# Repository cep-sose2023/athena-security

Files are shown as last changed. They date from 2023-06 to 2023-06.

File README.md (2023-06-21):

#  🎲 True Random Number Generator (TRNG) with PTG.2 Quality

Welcome to our GitHub page for the True Random Number Generator (TRNG) with PTG.2 quality standard. To ensure the quality of the random numbers, a creative noise source must be selected for each project, and the resulting random numbers must be digitized and processed according to the PTG.2 quality standard. The TRNG project includes three main components:

- **[NodeMCU: Sensor Data Sender](02-Microcontroller):** An Arduino sketch written in C++ for a NodeMCU development board that controls an LED and a fan, reads analog sensor data, and sends this data over a serial interface.
- **[Backend: Python Flask API](03-API):** A Python Flask API that supports system control, generates random numbers, and supports file downloads.
- **[Frontend: Angular Single-Page Application](04-Frontend):** An Angular Single-Page Application (SPA) that provides a user interface for system control, generating random numbers, and downloading files.

Each of these components has its own README file detailing its purpose, installation instructions, and usage. This README file serves as an overview of the entire project, and provides navigation to the individual component README files for more detailed instructions.

## ⭐ Features

The TRNG includes the following features:

- **System Control**: Ability to initialize, shut down, and restart the system.
- **Generate Random Numbers**: Generate random numbers based on user-provided parameters (number of bits and quantity).
- **Download Files**: Generate downloadable files of random numbers by specifying the number of bits and file type (binary or text).
- **Hardware Control and Data Transmission**: Ability to control an LED and a fan, read analog sensor data, and send this data over a serial interface using a NodeMCU board.

## 🛠️ Installation

Each component of the TRNG has its own installation instructions. Please refer to the individual README files for detailed installation steps:

- [NodeMCU: Sensor Data Sender  - Installation Instructions](02-Microcontroller#%EF%B8%8F-installation)
- [Backend: Python Flask API - Installation Instructions](03-API#%EF%B8%8F-installation)
- [Frontend: Angular Single-Page Application - Installation Instructions](04-Frontend#%EF%B8%8F-installation)

---

###  📸 Pictures

TRNG1
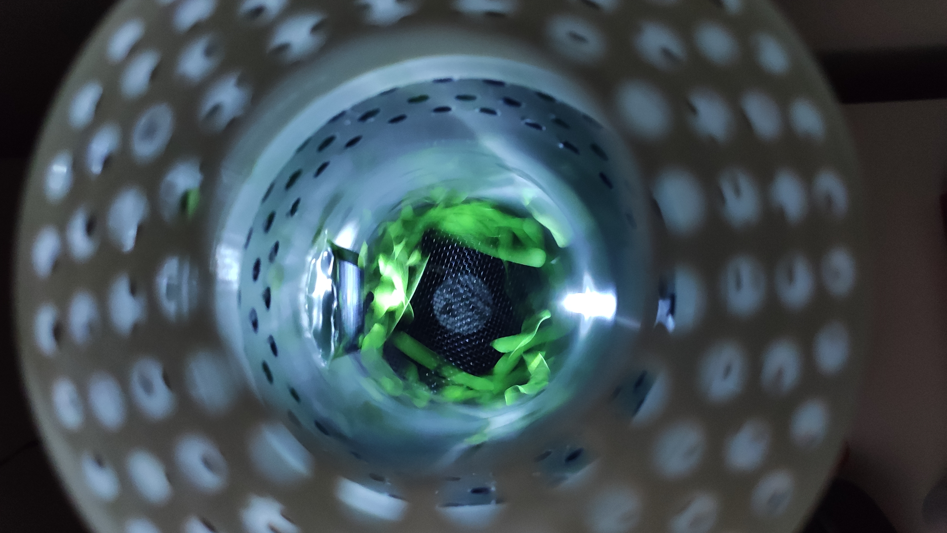
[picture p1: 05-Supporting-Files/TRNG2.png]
TRNG2


---

### 📖 License

This project is licensed under the MIT License. See the [LICENSE](LICENSE) file for details.

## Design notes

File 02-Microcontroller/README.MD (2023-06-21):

# TRNG: NodeMCU Sensor Data Sender

This is an Arduino sketch written in C++ for a NodeMCU development board, a low-cost open-source IoT platform. It leverages built-in functionalities of the NodeMCU to control an LED and a fan, read analog sensor data, and send this data over a serial interface. The program reads the solar voltage from a sensor, extracts the least significant bits (LSBs), and sends them over the serial interface.

## 🖨️ Technologies Used

This project is built using:

- **Arduino IDE:** A software platform used for writing and uploading code to development boards, which are part of electronics projects. The Arduino IDE provides a comprehensive toolset for microcontroller programming, simplifying the process of coding and debugging.
- **C++:** The main programming language used in the Arduino IDE.
- **NodeMCU:** An open-source IoT platform. It includes firmware which runs on the ESP8266 Wi-Fi SoC from Espressif Systems, and hardware which is based on the ESP-12 module.

## ⭐ Features

The NodeMCU code includes the following features:

- 🖥️ **LED & Fan Control:** Ability to turn ON and OFF the LED and the fan by receiving commands over the serial interface.
- 📊 **Analog Sensor Reading:** The program reads the solar voltage from an analog sensor, processes the reading, and converts it to an integer.
- 📡 **Data Transmission:** The program transmits the processed sensor data over the serial interface.

## 🛠️ Installation

This project was written in the Arduino IDE. To run the code on your NodeMCU, make sure you have the following requirements:

- **Arduino IDE:** Arduino IDE is a software used to write and upload the program to the NodeMCU board. Download and install Arduino IDE from the [official website](https://www.arduino.cc/en/software).
- **NodeMCU ESP8266:** The sketch is intended to be run on a NodeMCU board. You can purchase the board from any reputed electronics supplier.

 After you have the necessary tools, follow these steps:

1. **Clone the repository:**

   ```bash
   git clone https://github.com/athena-security/cep.git
   ```

2. **Open the sketch in the Arduino IDE:** Navigate to the downloaded location and open the "nodemcu.ino" file.

3. **Set up the board:** Go to File > Preferences, in the "Additional Boards Manager URLs" field, add this link: "http://arduino.esp8266.com/stable/package_esp8266com_index.json" and click OK. Now, go to Tools > Board > Boards Manager, search for ESP8266 and install it. 

4. **Select the board:** Go to Tools > Board > ESP8266 Boards > NodeMCU 1.0 (ESP-12E Module).

5. **Select the port:** Go to Tools > Port > Select the COM Port that the NodeMCU is connected to.

6. **Upload the sketch:** Click on the upload button (->) or select Sketch > Upload from the menu.

Once the upload is complete, the LED and the fan should respond to "on" and "off" commands sent over the serial interface, and transmit processed sensor data when active.

⚠️ Note: Ensure you have the necessary components and have configured the NodeMCU board correctly before uploading the code. A complete construction manual with a schematic also exists in this repository.

## License

This project is licensed under the [MIT License](../LICENSE.md).

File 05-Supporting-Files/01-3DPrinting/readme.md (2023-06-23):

The visible cover must be printed together with a closure. Both STL-files for 3D printing can be downloaded here. In addition, the files for Autodesk Fusion 360 can also be downloaded here to customize both parts if needed.
<br><br><br>
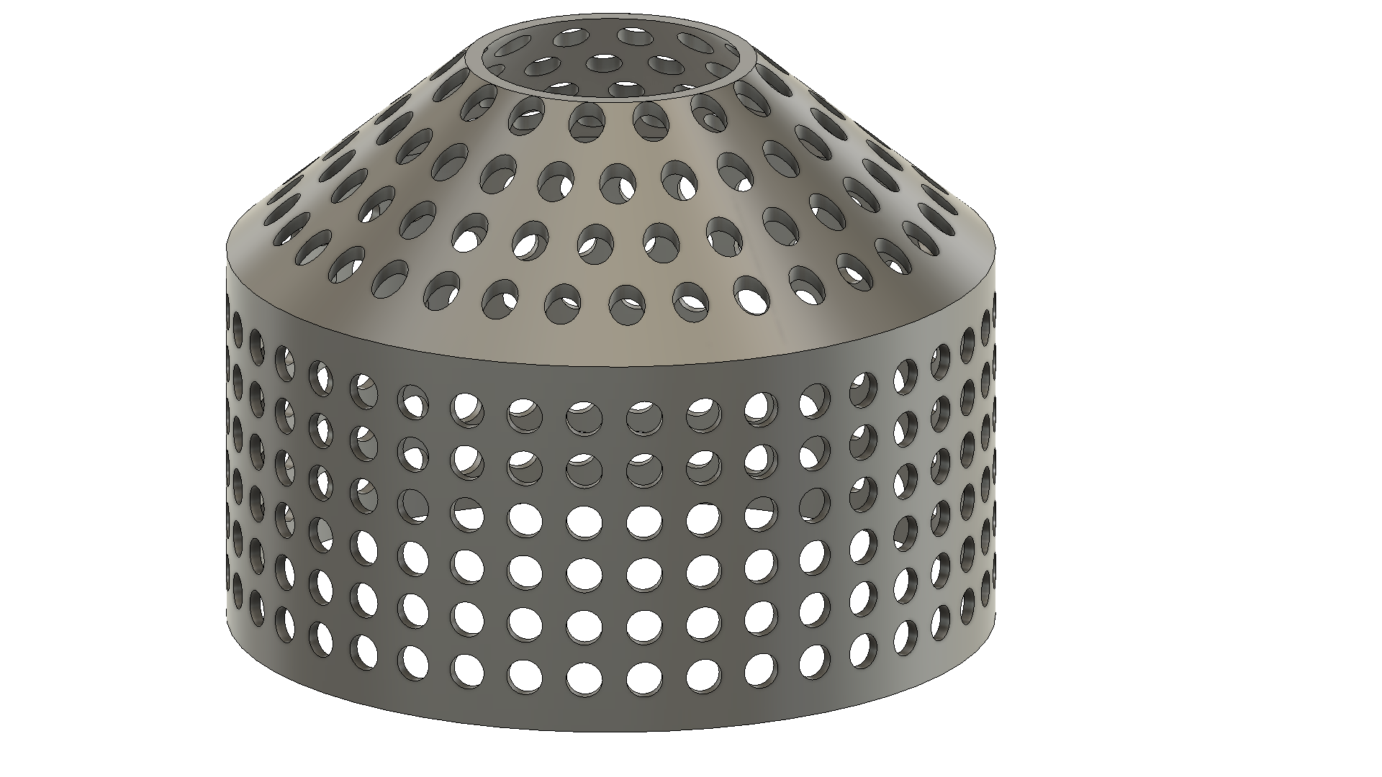
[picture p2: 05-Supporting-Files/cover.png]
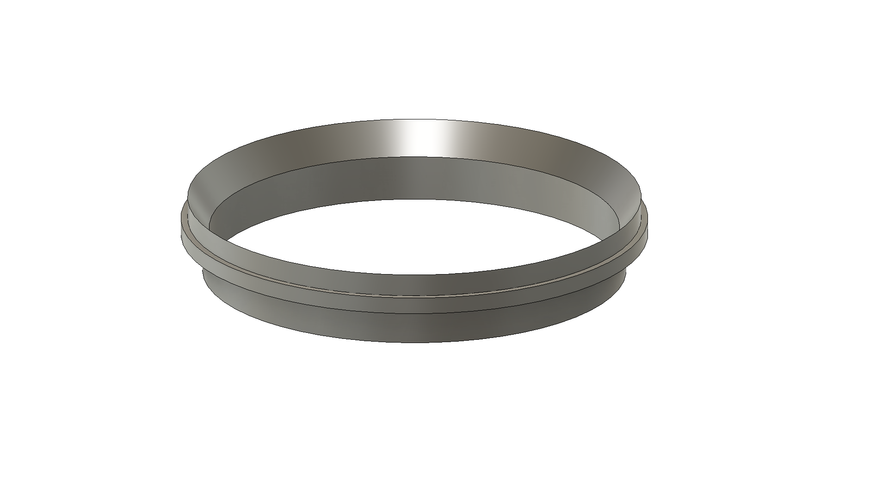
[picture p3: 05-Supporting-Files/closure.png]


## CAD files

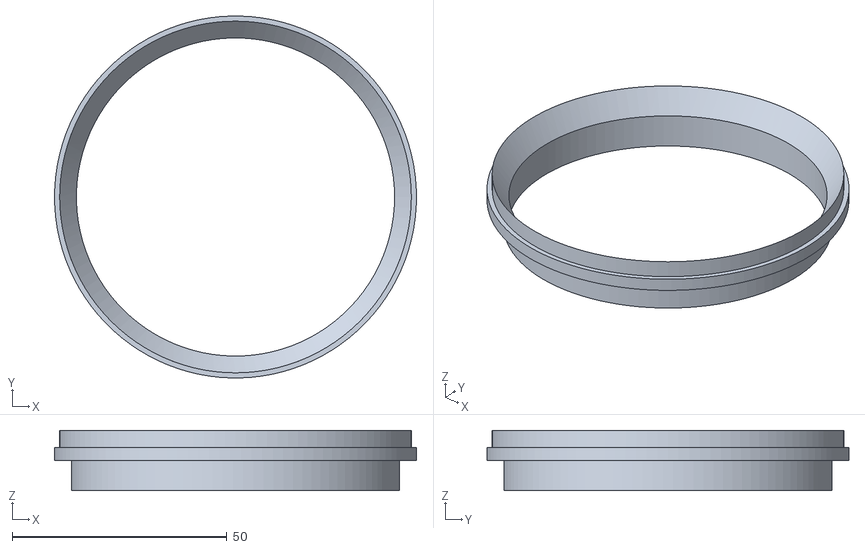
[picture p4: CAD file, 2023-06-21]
05-Supporting-Files/01-3DPrinting/closure.stl
84.2 x 84.2 x 14.0

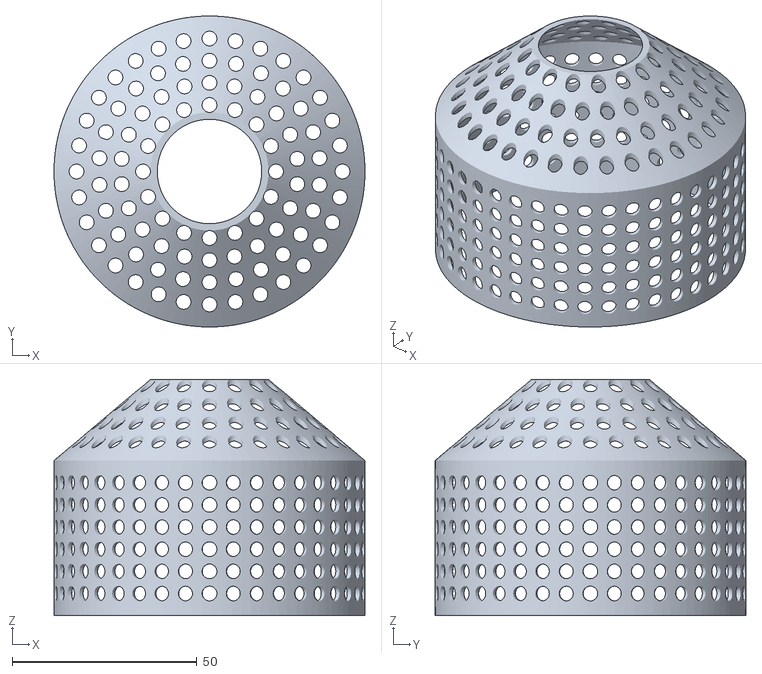
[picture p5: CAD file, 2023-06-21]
05-Supporting-Files/01-3DPrinting/cover.stl
84.2 x 84.2 x 64.0

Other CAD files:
05-Supporting-Files/01-3DPrinting/Autodesk Fusion 360 files/closure.f3d
05-Supporting-Files/01-3DPrinting/Autodesk Fusion 360 files/cover.f3d

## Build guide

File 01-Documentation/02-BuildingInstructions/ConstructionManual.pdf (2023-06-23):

## 14. JUNE 2023

## TRUE RANDOM NUMBER GENERATOR

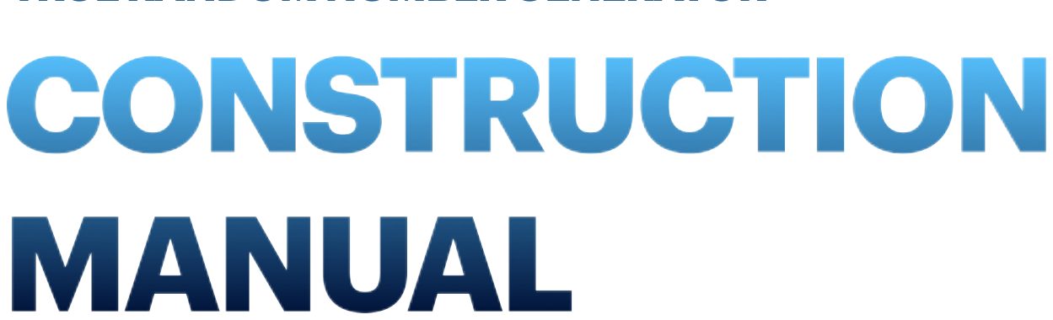
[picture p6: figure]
CONSTRUCTION MANUAL

TRUE RANDOM NUMBER GENERATOR | USER GUIDE

# AthenaSecurity

## PARTICLES IN A WIND TUNNEL

## TABLE OF CONTENTS

Introduction | 2
Materials And Tools Needed | 3
Preparation | 6
Step By Step Guide | 8

### 1 ATHENASECURITY

## INTRODUCTION

This step by step guide will show you how to build a true random number generator that should pass the BSI AIS 31 statistical tests suite. Round paper snippets are used here as the noise source, which are made to fly by a normal PC fan. The generated numbers can be queried via a REST interface. In addition to this build guide, there is documentation for the software code used, as well as for using the REST interface. All relevant documents, as well as the software code can be found here: https://github.com/cep-sose2023/athena-security.

### 2 ATHENASECURITY

## MATERIALS AND TOOLS NEEDED

## MATERIALS

- Hot glue gun
- NodeMCU v1 development board
- 2xHTEMDN75x1.9
- Micro-USB – USB-A Cable
- 3D-Printing PLA Filament ≥ 40 g
- 1m cable 30AWG with insulation
- Delta AFC0712DB 0.45A DC12V Fan
- LM2596S DC-DC 4,5-40V step-down power Supply module
- 4 x M4 47mm screws with nuts
- Power Supply DC24V
- Resistors(1x47Ω|1x4.7kΩ|2x10kΩ)
- 5Vsolarcell53mmx30mm
- 5 mm LED white
- Velind Anti-Static spray
- Photo mounting board paper 270 g/m2
- Mosquioto net 150 cm2
- BC337 45V 800mA NPN Transistor

### 3 ATHENASECURITY

- BSS84 P-Channel Mosfet
- Soldering tin
- Sandpaper
- Cardboard with 1 mm thickness
- Hot glue sticks
- Breadboard 45 mm x 34.5 mm (optional)
- Cable ties (optional)
- Paint spray blue (optional)

### 4 ATHENASECURITY

## TOOLS

- 3D-Printer
- Hot glue gun
- Drill Bits Ø 1/2/3/4 mm
- Countersink
- Cordless screwdriver
- Soldering Iron
- Wire stripping tool
- Flat nose pliers
- Side cutter
- Screwdriver
- Scissors
- Hole punch
- Angle grinder
- Multimeter
- Felt pen
- Ruler
- Electronic scale

### 5 ATHENASECURITY

## PREPARATION

## PREVIOUS KNOWLEDGE REQUIRED

- Basic craft skills
- Arduino knowledge
- Soldering
- 3D printing

## COVER (3D-PRINTING)

Needed material for this step: 3D-Printer, ≥ 40 gram PLA filament

The cover for the wind tunnel consists of two parts, which can be 3D printed. The visible cover must be printed together with a closure. Both STL-files for 3D printing can be downloaded here: https://github.com/cep-sose2023/athena-security

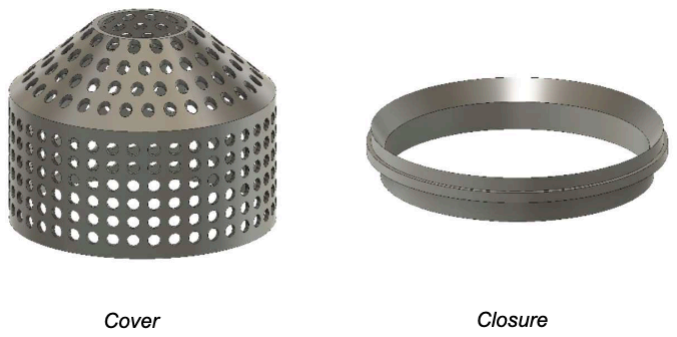
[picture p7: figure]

## TUBEES (CUTTING)

Needed material for this step: 2 x HTEM DN 75 x 1.9, angle grinder, felt pen, sandpaper

The two HT tubes must be cut to the correct length before assembly. An angle grinder, for example, can be used for the cut. It is recommended to mark the correct position

### 6 ATHENASECURITY

for the cut with a felt pen beforehand. The cut must be made on the open side of both tubes. Tube 1 should be cut to a length of 15 cm and tube 2 to a length of 16 cm.

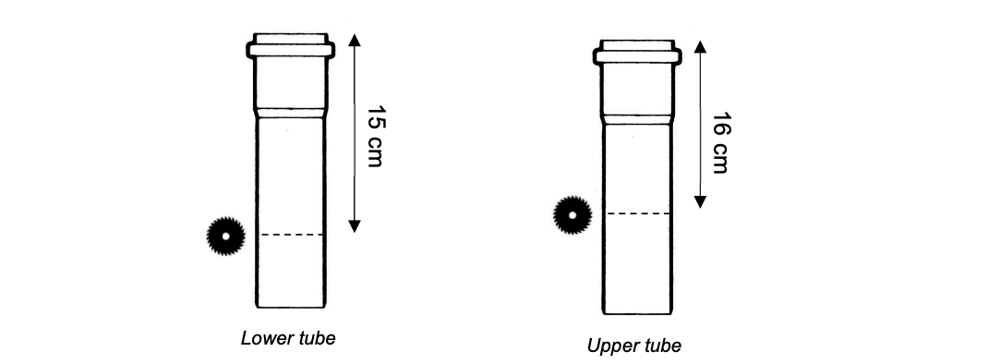
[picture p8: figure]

After both tubes are cut to the correct length, it is recommended to sand the cut edges with sandpaper. As an optional step, the two tubes can also be sprayed with a paint here.

### 7 ATHENASECURITY

## STEP BY STEP GUIDE

After the chapter "Preparation" has been completed, the main components consisting of the two tubes and the 3D-printed cover should be ready. The following steps show the rest of the assembly and should be followed in the correct order.

## 1. DRILL HOLES FOR LESS WIND RESISTANCE

Needed material for this step: drill bits Ø 1/2/3/4 mm, countersink, cordless screwdriver

Holes can be drilled in the top tube to give the air more opportunity to escape, and thus also to run the fan at a lower speed and with less noise.

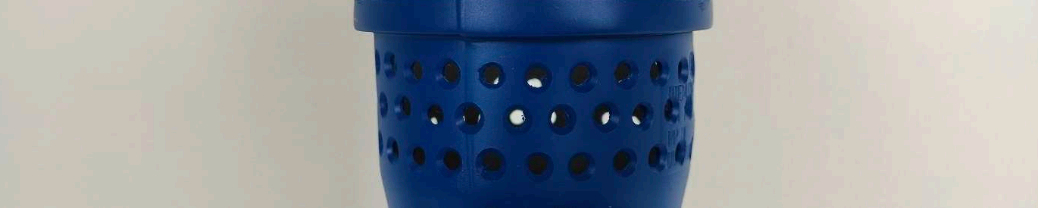
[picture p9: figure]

A template for the holes can be found at the following link: https://github.com/cep-sose2023/athena-security (https://github.com/cep-sose2023/athena-security) .This template should be printed and cut out. It can then be glued to the upper end of the tube with adhesive tape.

It is then recommended to pre-drill with 1 mm in order to reach the desired 4 mm holes with the further drills. After the 4 mm holes are finished, it is recommended to improve each hole with a countersink.

### 8 ATHENASECURITY

## 2. DECREASE AIR ROTAION

Needed material for this step: hot glue gun, scissors, ruler, cardboard 1 mm thickness, prepared tube from earlier

The air that flows out of the fan has a rotary motion, which means that snippets can remain in the center and are not caught by the wind. To prevent this, a piece of cardboard is glued a few centimeters above the fan, which takes the rotation out of the air.

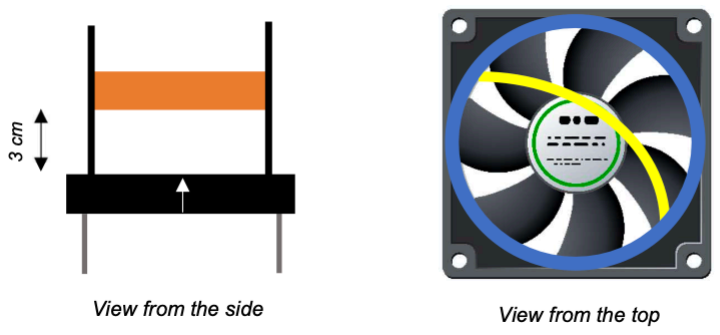
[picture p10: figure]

The cardboard used has a thickness of 1 mm. The piece of cardboard used was cut to a length of 80 mm and a height of 20 mm. After cutting, it should be glued about 3 cm above the end of the lower tube. A hot glue gun was used for gluing. The fan is attached to the tube at a later stage.

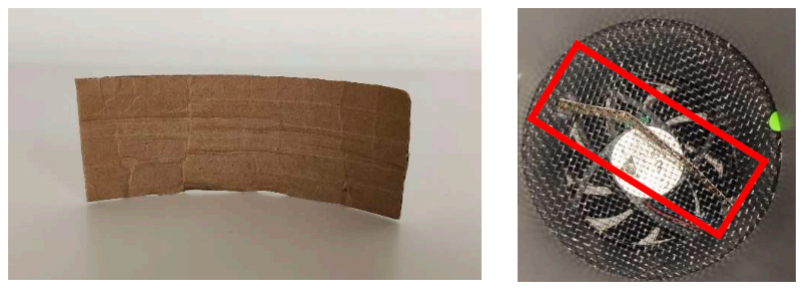
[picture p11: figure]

### 9 ATHENASECURITY

## 3. INSTALL SOLAR CELL AND LED

Needed material for this step: 5V solar cell 53 mm x 30 mm, 5 mm LED white, cable, cordless screwdriver, drill bits, hot glue gun, ruler, upper tube

First, mark a point 6 cm above the end of the tube with a felt pen. There the hole for the cables of the solar cell should be drilled. The diameter to be drilled here should be 2 mm.

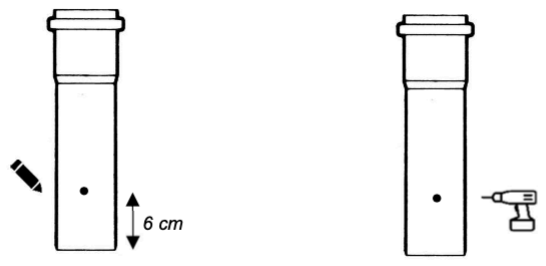
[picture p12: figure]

After the hole is drilled, it is time to glue the solar cell inside the tube, passing the cables through the hole that has just been drilled. A hot glue gun can be used for gluing.

The LED must now be installed on the opposite side of the solar cell. To do this, a hole is drilled on the opposite site and at the same height with a 5 mm drill. The LED is then inserted through the drilled hole and glued from the outside with hot glue.

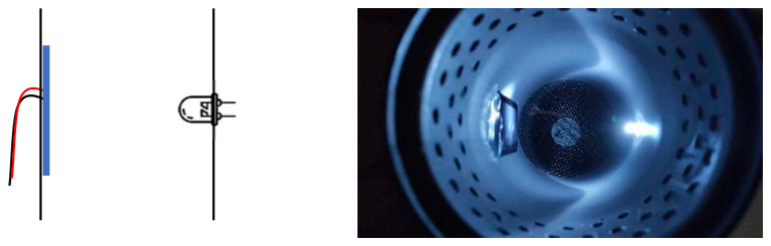
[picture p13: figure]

The wiring of the two components will be covered at a later time.

### 10 ATHENASECURITY

## 4. CONNECT THE TWO TUBES

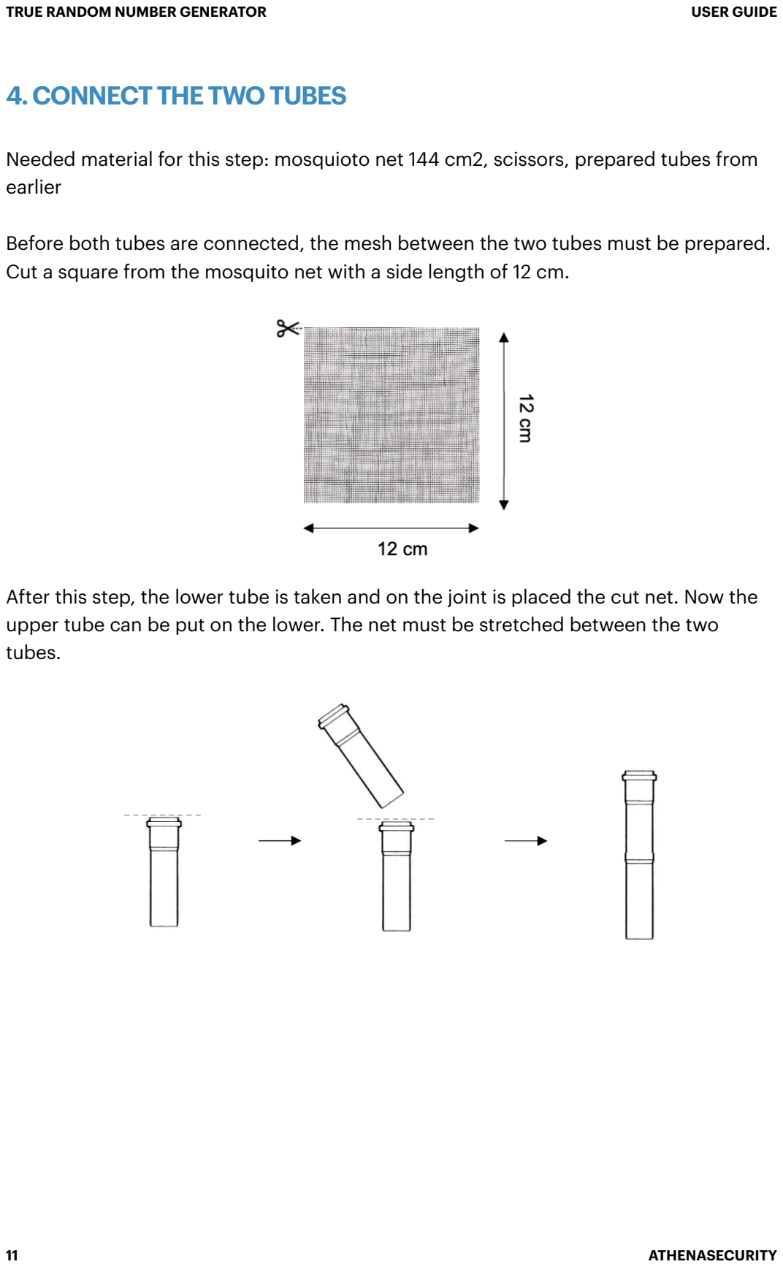
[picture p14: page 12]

Needed material for this step: mosquioto net 144 cm2, scissors, prepared tubes from earlier

Before both tubes are connected, the mesh between the two tubes must be prepared. Cut a square from the mosquito net with a side length of 12 cm.

After this step, the lower tube is taken and on the joint is placed the cut net. Now the upper tube can be put on the lower. The net must be stretched between the two tubes.

### 11 ATHENASECURITY

## 5. INSTALLING THE FAN

Needed material for this step: hot glue gun, fan DC12V, 4 x screws M4 47 mm with nuts

Find out the wind direction of the fan, making sure that the wind direction is upwards. Then insert the four screws together with the matching nuts through the holes on the fan. The fan should stand firmly on the base and not wobble. Then you can put the wind tunnel on the fan and glue it with a hot glue gun from the outside. Make sure that there are no more openings between the fan and the tube.

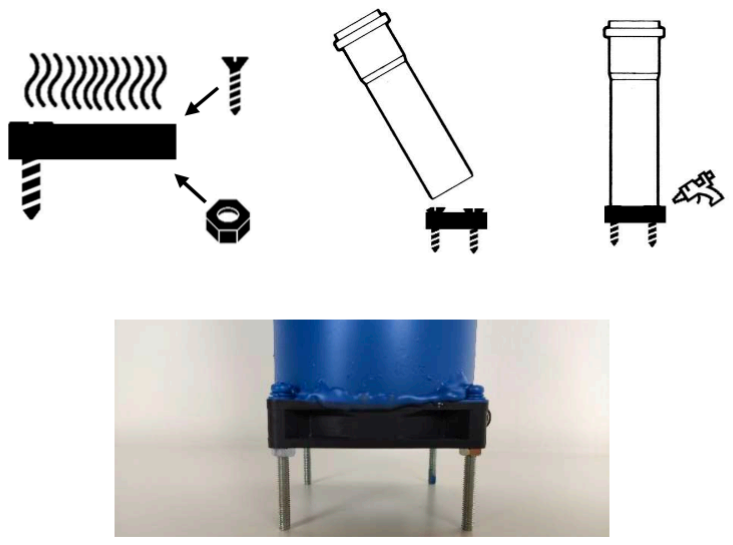
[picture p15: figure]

### 12 ATHENASECURITY

## 6. MOUNTING THE MICROCONTROLLER

Needed material for this step: NodeMCU development board, small breadboard 45 mm x 34.5 mm (optional), cable ties (optional)

In the first step, plug the microcontroller onto the breadboard. You can then fix the breadboard with cable ties around the wind tunnel. It is recommended to have the USB connector of the microcontroller pointing to the right to make this instruction easier to follow.

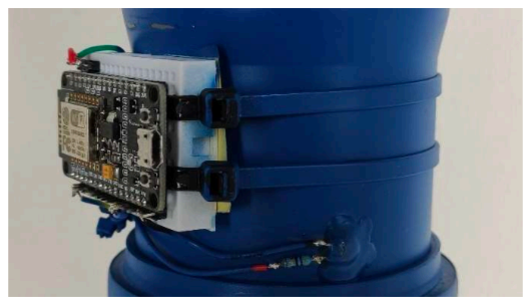
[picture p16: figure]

If you don't have a breadboard or cable ties available, you can also attach the NodeMCU board to the wind tunnel with hot glue. Make sure that the pins of the microcontroller are not covered with hot glue from above.

### 13 ATHENASECURITY

## 7. WIRING OF THE SOLAR CELL AND THE LED

Needed material for this step: wire, side cutter, soldering iron, 47Ω resistor

The positive pole of the solar cell is soldered to pin A0 of the NodeMCU. A circuit diagram can be found in the chapter "Logical circuit diagram and structure". The ground pin is then soldered to the lower GND pin on the NodeMCU.

The anode side of the LED can be determined with a multimeter. It should be soldered in series with a 47Ω resistor to pin D2 on the NodeMCU. The cathode side should be soldered to a GND pin on the NodeMCU.

### 14 ATHENASECURITY

## 8. ATTACHING THE STEP-DOWN POWER SUPPLY & SOLDERING THE TRANSISTOR

### 8.1 ATTACHING THE STEP-DOWN POWER SUPPLY

Needed material for this step: LM2596 DC-DC module, power supply DC24V, multimeter, hot glue gun

The correct fan speed is crucial for the correct function of the random number generator. Optimum air flow can be set by varying the supply voltage of the 12 V fan. A prefabricated LM2596 DC-DC converter module converts the 24 V DC input voltage into the required fan voltage. The fan voltage, the fan speed and the air flow are adjusted with a potentiometer on the DC-DC converter module.

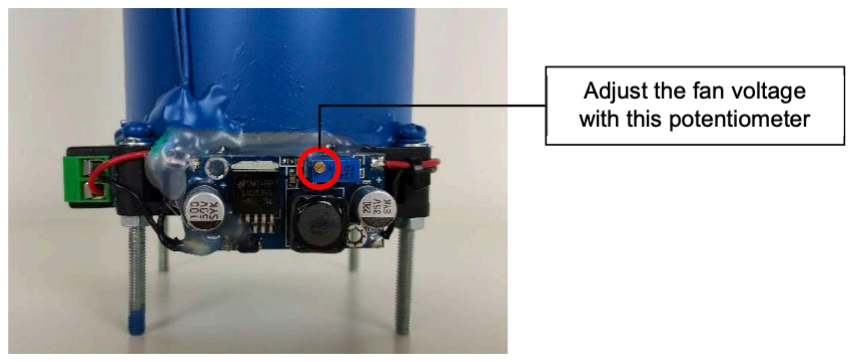
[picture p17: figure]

The DC-DC converter module can be glued to any side of the fan with hot glue. Before the DC-DC converter is wired and put into operation, you should make sure that the set output voltage is not too high for the fan. An output voltage of 12V is
recommended for a first test. To set the potentiometer correctly, connect the DC-DC module to a power supply and measure the output voltage with a multimeter.

In order to be able to switch the fan on and off via the software, the 24 V supply voltage is fed via a transistor / mosfet circuit into the DC-DC converter module. The wiring of this circuit will be discussed in more detail in the next chapter.

### 15 ATHENASECURITY

### 8.2 SOLDERING THE TRANSISTOR / MOSFET CIRCUIT

Needed material for this step: multimeter, hot glue gun, soldering iron, wire, BC337
45V 800mA NPN Transistor, BSS84 P-Channel Mosfet, resistors (2 x 10 kΩ | 1 x 4.7 kΩ),
side cutter

To follow the steps it is recommended to have a look at the section "Logical circuit diagram and structure". The following part is for simple on/off switching of the DC-DC module using the microcontroller. This works by the micocontroller switching the base voltage of the mosfet Q3 with the help of the transistor Q2. Mosfet Q3 can then switch through the 24V supply voltage to the DC-DC converter module. To achieve this you can follow the steps below

Connect Controller Pin D1 to Q2's Base Pin: Connect the controller pin D1 to the base pin of the transistor Q2 through resistor R4. This will allow the microcontroller to control the transistor Q2.

Connect 24V Supply to Q3's Source Pin: Connect the 24V power supply input to the source pin of the PNP MOSFET Q3.

Connect Q3's Drain Pin to the DC-DC Converter Module: Connect the drain pin of Q3 to the Vin input of the DC-DC converter module. This allows the MOSFET to direct power to the converter module when it switches on.

Connect 24V Supply to Q2's Collector Pin: Connect the 24V power supply input to the collector pin of transistor Q2 via resistors R5 and R6. This allows the power to flow through Q2 when the transistor is in the ON state.

Connect the Line between R5 and R6 to Q3's gate: The line between resistors R5 and R6 should be connected to the gate of MOSFET Q3. This will control the switching of the MOSFET and sets Q3 to be able to switch the DC-DC converter module.

Connect 0V Line of Power Supply to Various Components: Connect the 0V line of the 24V power supply to the controller GND, the emitter of transistor Q2, and the negative input pin of the DC-DC converter module. This completes the return paths for the currents in the circuit and establishes a common ground.

The whole circuit can be fixed and protected with hot glue afterwards. Loose cable pairs can be brought together with cable ties.

### 16 ATHENASECURITY

## 9. PUNCHING THE ROUND PAPER SNIPPETS

Needed material for this step: Photo mounting board paper 270 g/m2, hole punch, electronic scale, anti-static spray

For this section, it is important that the paper thickness is chosen correctly. Paper that is too thin can cause snippets to stick due to electrostatic charge. Paper that is too thick will make the snippets too heavy for the intended use. Photo mounting board paper with a weight of 270 g/m2 has proven to be suitable. Punch out 0.56 g of round paper snippets with a hole punch and fill the wind tunnel with them.

### 17 ATHENASECURITY

## 10. LOGICAL CIRCUIT DIAGRAM AND STRUCTURE

### 10.1 LOGICAL CIRCUIT DIAGRAM

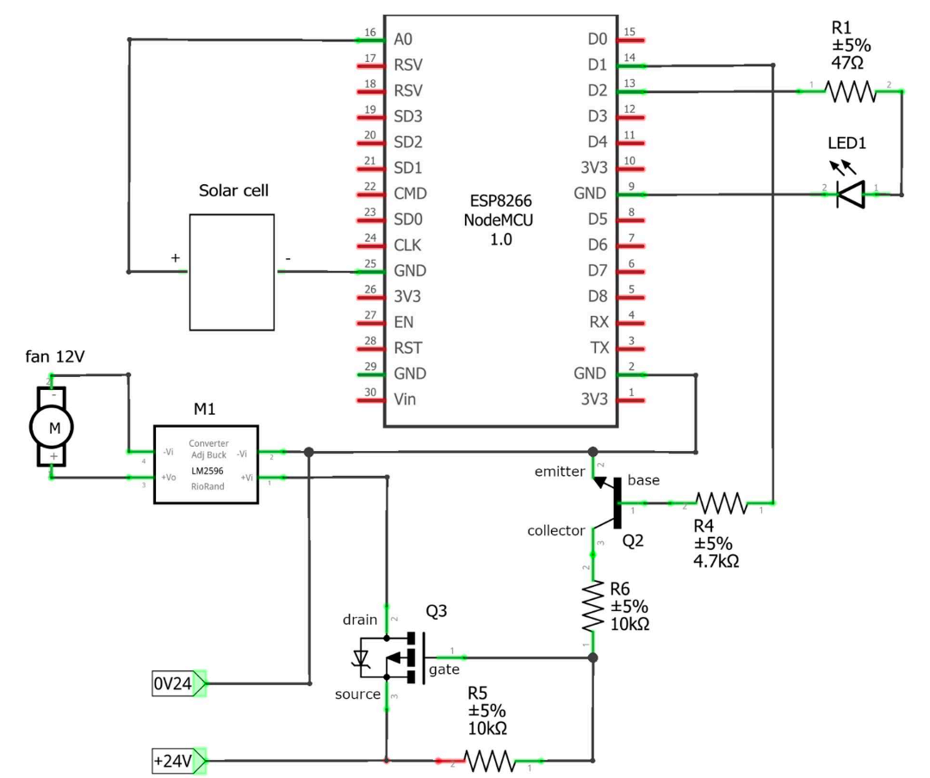
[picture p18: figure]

### 18 ATHENASECURITY

### 10.2 STRUCTURE

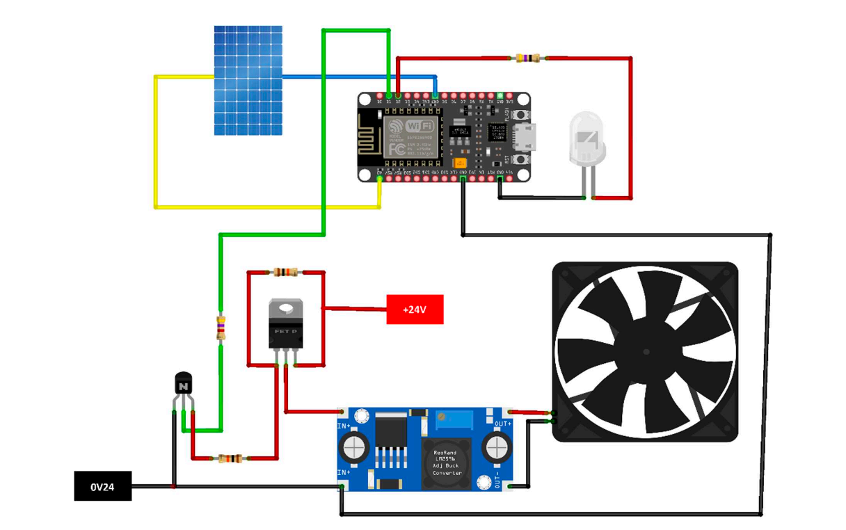
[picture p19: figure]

### 19 ATHENASECURITY

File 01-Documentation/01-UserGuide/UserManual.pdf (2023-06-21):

## 14. JUNE 2023

# TRUE RANDOM NUMBER GENERATOR

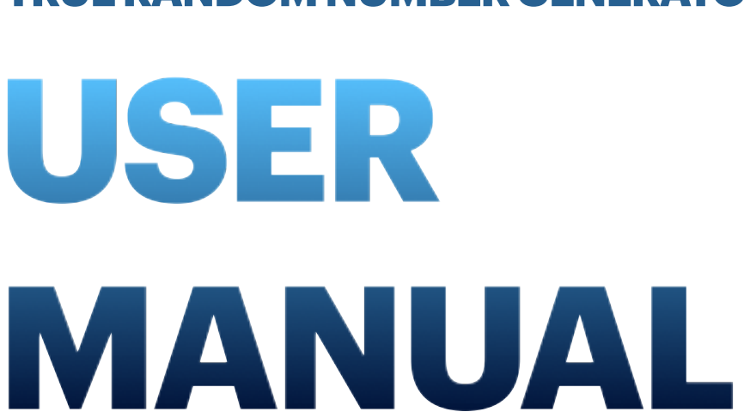
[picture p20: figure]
USER MANUAL

TRUE RANDOM NUMBER GENERATOR | USER GUIDE

# AthenaSecurity

## PARTICLES IN A WIND TUNNEL

# TABLE OF CONTENTS

Introduction | 2
System Architecture Documentation | 3
Interface Specifications | 6
Statistical Tests | 9
Security Considerations | 13
Environment Setup | 14
User Interface | 15
Conclusion | 23
Appendix A - Endpoints | 24
Appendix B - Environment Setup | 25

### 1 ATHENASECURITY

# INTRODUCTION

This user guide provides detailed insights into the functioning of a Python-based

true random number generator (TRNG). The TRNG operates using a Flask An application programming interface (API) that facilitates communication over a serial connection with a dedicated hardware device. This device's primary role is the generation of random numbers, which are then served to an Angular-based frontend application.

The design and functionalities of this True Random Number Generator (TRNG) follow the specifications and guidelines presented in the Bundesamt für Sicherheit in der Informationstechnik (BSI) paper titled "A proposal for: Functionality classes for random number generators - Version 2.0". (https://www.bsi.bund.de/SharedDocs/Downloads/DE/BSI/Zertifizierung/Interpretationen/AIS_31_Functionality_classes_for_random_number_generators_e.pdf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) This reference document provides a comprehensive framework for designing, implementing, and evaluating random number generators. Our system is designed to comply with these standards, ensuring the production of high-quality random numbers suitable for various applications.

### 2 ATHENASECURITY

# SYSTEM ARCHITECTURE DOCUMENTATION

The system architecture of the application comprises three main components: a backend Flask application, a hardware device serving as a random number generator, and a frontend Angular application.

The Flask application acts as an intermediary, facilitating communication between the software and the hardware random number generator via the serial port. Utilizing the Python serial module, the Flask application can send specific commands to the hardware device, including initialization, shutdown, and restart operations.

Once the hardware device is initialized, it continuously generates random bits, which are buffered in the serial input buffer. When a request for random numbers is received, the Flask application reads the random bits from the buffer. These bits are then parsed and converted into hexadecimal values, resulting in an array of hexadecimal strings as the output. Additionally, the Flask application offers the ability to generate a file containing random test data based on user-defined parameters. Users can choose between binary or text format for the generated file.

To serve the Flask API, a Gunicorn server is employed. This Python WSGI Hypertext Transfer Protocol (HTTP) server is known for its simplicity and high performance. The Flask API runs on the localhost at port 8000 and is reverse-proxied by an Nginx server block listening on port 8443. This reverse proxy configuration provides added flexibility and enhances security.

Furthermore, the system utilizes a Python virtual environment to manage dependencies. This practice ensures that the project's packages remain isolated and do not interfere with those of other Python projects. By keeping dependencies contained within the virtual environment, the system promotes a more robust and error-free development and deployment process.

On the frontend side, the application is developed using Angular, a powerful framework for building single-page applications (SPAs). The Angular frontend is hosted on an Nginx server listening on port 443. Nginx is recognized for its stability, rich feature set, and e#icient resource consumption, making it an ideal choice for serving the Angular application.

To ensure secure communication, SSL/TLS (Secure Sockets Layer/Transport Layer Security) encryption is implemented for all tra#ic to and from the servers. Self-signed

### 3 ATHENASECURITY

certificates generated using OpenSSL are used for this purpose. Additionally, the system is configured with a static IP address of 172.16.78.59 for the system network interface 'eth0', establishing a stable networking environment that enables reliable communication.

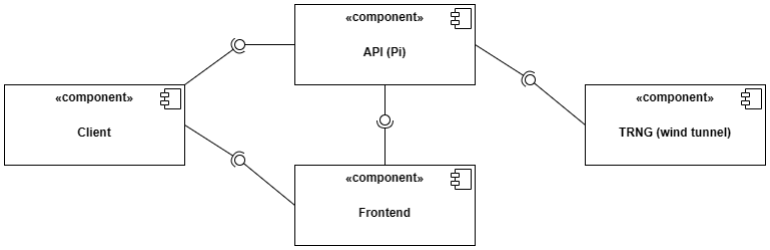
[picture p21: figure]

This diagram showcases the interaction between the system components. The Angular application communicates directly with the Flask API, which, in turn, communicates with the hardware device. A more detailed representation of this setup can be found in the accompanying UML deployment diagram:

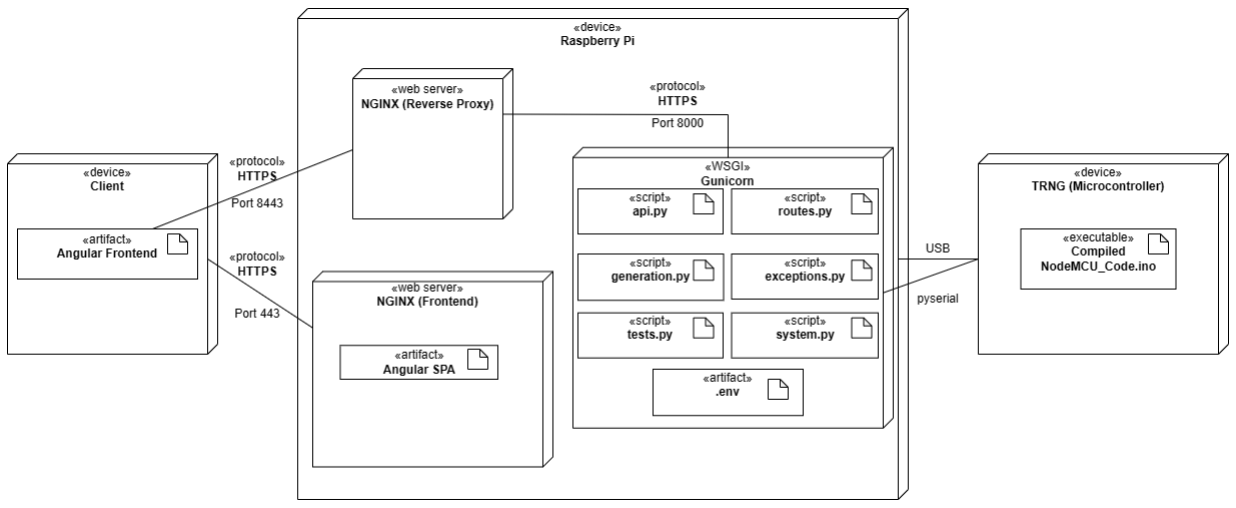
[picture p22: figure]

Here we can see, that the Raspberry Pi acts as the central node and deploys three servers. The first server is the Gunicorn WSGI server, responsible for handling all API requests. These requests are passed on by the second server, the NGINX reverse proxy

### 4 ATHENASECURITY

UML Component Diagram

UML Deployment Diagram server, which therefore serves as an intermediary. The Angular Frontend submits requests to the NGINX reverse proxy, benefiting from its routing capabilities. The third server is dedicated to serving the Angular application independently. Additionally, the

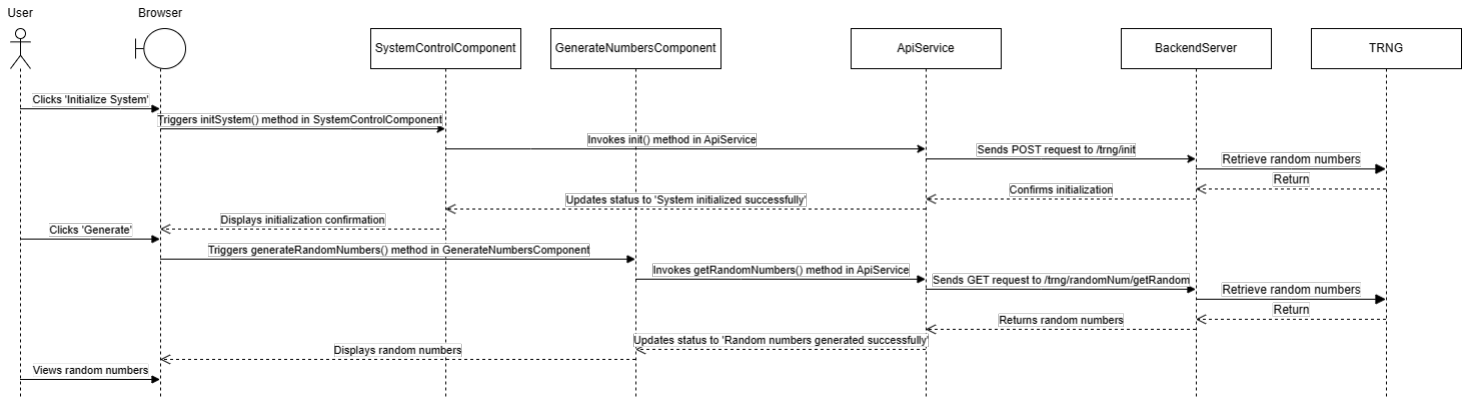
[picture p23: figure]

diagram depicts the serial USB connection between the Raspberry Pi and the TRNG hardware device.

The sequence diagram provided above outlines the primary workflow of the system. A user interacts with the Angular application, which subsequently sends requests to the Flask API. The API, in turn, communicates with the hardware device, performing actions such as generating random numbers based on the user's request.

In summary, this architecture provides a secure, scalable, and performant setup for serving the Angular application and Flask API to the end users, and ensures a smooth, e#icient workflow for developers. It is designed to provide a flexible, reliable, and secure way of generating random numbers through a hardware device, allowing for a diverse range of uses in various applications.

### 5 ATHENASECURITY

UML Sequence Diagram

# INTERFACE SPECIFICATIONS

## API ENDPOINTS

The system architecture comprises of several key parts working together to offer a seamless user experience. At the heart of the backend is a Flask microservice written in Python. Flask's simplicity and flexibility allow us to develop a lightweight API for our application, where several routes and functionalities are defined. The Flask API exposes several endpoints for interaction.
- init: Initializes the hardware random number generator.
- getRandom: Returns randomly generated numbers.
- generateTestdata: Generates a test data file with random numbers.
- downloadFile: Downloads the generated test data file.
- shutdown: Shuts down the hardware random number generator.
- restart: Restarts the hardware random number generator.

Each of these endpoints can be mapped to a use case, which are visualized in the UML use case diagram below.

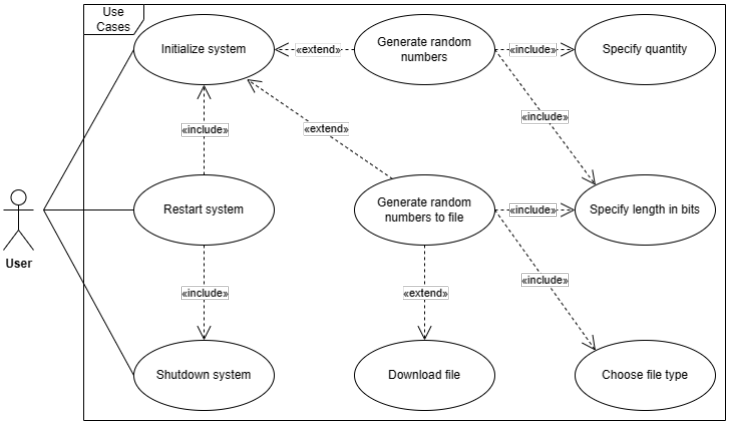
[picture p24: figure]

### 6 ATHENASECURITY

UML Use Case Diagram

The Flask API returns a HTTP status code of 200 for any successfully satisfied request. Other than that, the system can be in various states of errors. Below is a list of HTTP response codes used by the Flask API to signalize errors.

1. 404: The requested page was not found. Check the URL in the address bar of the Browser for typing errors.
2. 409: This response occurs if users send an initialization request, when the system has already been initialized.
3. 432: This response occurs if users try to generate random number, when the system is not initialized.
4. 555: This response can either occur if the Flask API loses connection to the serial device (TRNG) or if an error occurs during the generation of random numbers (e.g. detection of a total failure).

Comprehensive details regarding the individual endpoints of our system, covering both their functions and operations, can be located in Appendix A - Endpoints. This section delves into an extensive exploration of each endpoint, their potential responses, and scenarios of usage. It should be referred to for a thorough understanding of how to correctly interact with our system's endpoints.

## SERIAL INTERFACE

Serial communication between the Flask API and the hardware device is facilitated by a configuration file. This file aids in setting up the specific parameters required for the correct establishment of the connection. Here's an example of the syntax to be used within this file:

port = "/dev/ttyUSB0"
baud_rate = 9600

In this configuration:
- port: This line specifies the serial port used to establish the connection with the

hardware device. On a Unix-based system like Linux, this is typically designated as "/dev/ttyUSB0" or similar, depending on the specific hardware setup. You can determine the exact port being used by executing the command “ls /dev” in the

### 7 ATHENASECURITY

terminal. This will list all device files, and your serial device will generally appear as "/dev/ttyUSB*" or “/dev/ttyACM*”.
- baud_rate: This line designates the speed of the data transfer in bits per second. In

this example, a baud rate of 9600 is used, which is a common default for many devices. However, the specific baud rate would depend on your device's specifications.

By using this configuration file, the Flask API can successfully establish a reliable serial communication channel with the hardware device, allowing for e#icient data exchange and interaction.

### 8 ATHENASECURITY

# STATISTICAL TESTS

## TEST SUITES

The statistical validity of the numbers produced by the True Random Number Generator (TRNG) has been thoroughly examined, yielding promising results. Notably, they satisfy the stringent reference standards of the German Federal O#ice for Information Security, also known as the Bundesamt für Sicherheit in der Informationstechnik (BSI). This was confirmed by passing tests T0 through T8 as defined in the BSI's guidelines, as per the AIS_31_testsuite, the recognised yardstick for assessing the quality of random number generators.

## IMPLEMENTED TESTS

One of the obligatory tests that is implemented and prescribed by the PTG.2 standard is the total failure test. This test is meant to detect a total breakdown of the entropy source. In our case, a total breakdown of the entropy source is present, when no snippets are moving in front of the solar cell. This could happen if the fan stops blowing for example. A situation like this will produce patterns or constant values as an output of the TRNG.

The total failure test implemented works as follows: The generation of random numbers is done in chunks of 100 bytes. The total failure test checks how many bytes are identical. A total failure is detected, if the amount of identical bytes exceeds a fixed value. The value needs to be determined in a way that it effectively detects a total failure, while not turning in a false alarm too frequently.

After testing the TRNG by simulating a total failure with the LED and fan turned off, we observed that a fixed value of six identical bytes proves to be a good trade between having a good rate of detection, while keeping the probability of a false alarm low. The probability for the event that the total failure test detects a total failure, even though there is none (i.e. the probability for an ideal RNG to produce such a result), can be calculated with the help of the cumulative binomial distribution function:

### 9 ATHENASECURITY

For this case n = 100, k = 6 and p = 1/256 as there are 2^8 = 256 different outcomes for a

random byte. As this would be the counter event of more than 6 identical bytes in 100, we can subtract this from 1, which leads to:

With this probability and the time it takes to conduct a total failure in seconds which is

for a bit generation rate of 60 per second (as 800 bits = 100 bytes are needed for a total failure test; time for computation is neglected), we can calculate the expected number of false alarms in a year with

where X: Number of false alarms, n is the number of total failure tests conducted in a year and

n can be calculated with

which leads us to

If we take the reciprocal of this number, we get

### 10 ATHENASECURITY

which means it would take on average 2.6144 years for this event to be expected once.

Furthermore, by calculating confidence intervals on the base of a random sample with 20,000 bytes, we could observe the probability of a total failure not being detected, even though there is one, to be between 3.0% to 3.8% with a confidence of 99.7%. This suggests that the determined fixed value allows the test to effectively detect a total failure.

## SOFTWARE TESTING

Our Representational State Transfer (REST) API has undergone manual testing procedures employing the flexible tool, "RESTer". This tool empowers users to dispatch a variety of HTTP requests to a REST interface, offering broad capabilities to manipulate HTTP headers and bodies.

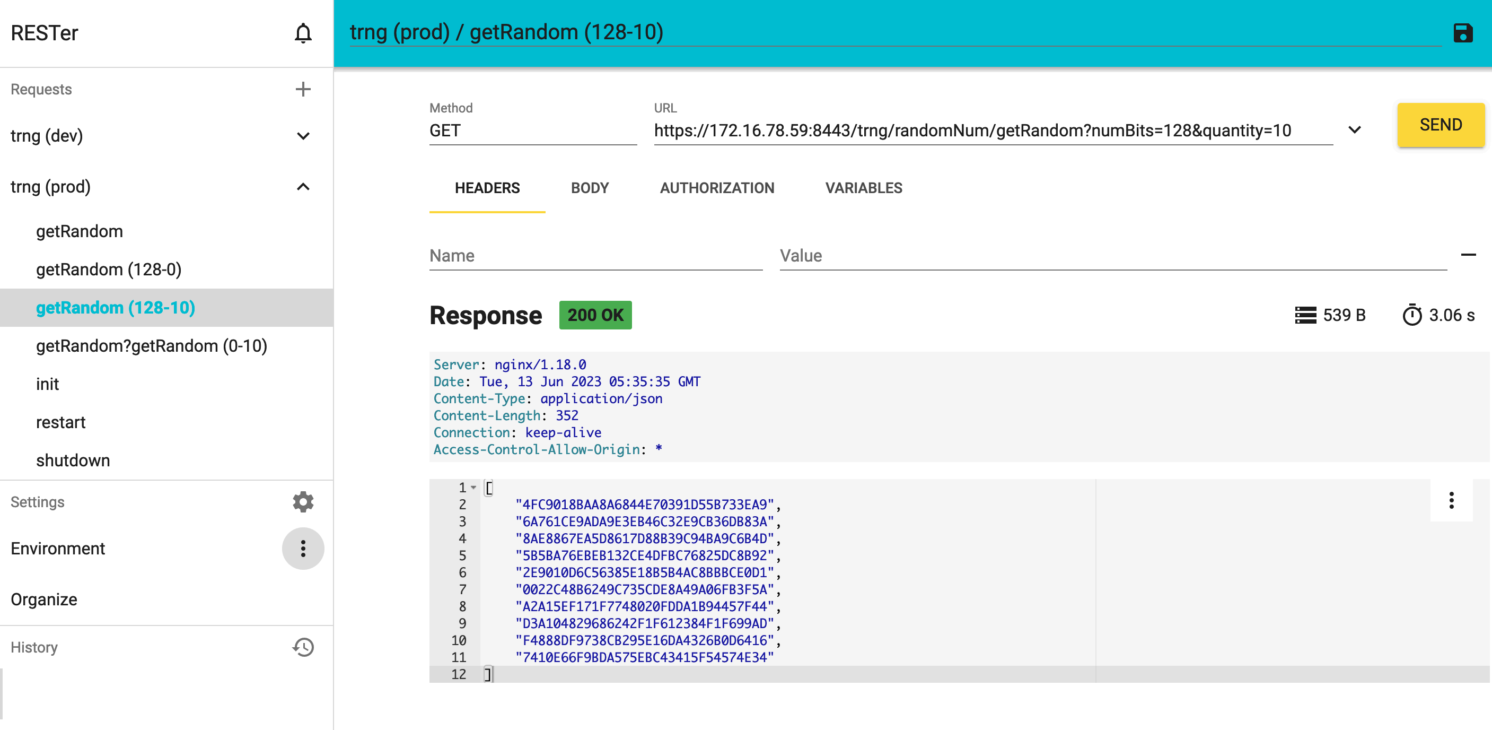
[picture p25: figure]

Additionally, "RESTer" offers a detailed perspective of responses obtained from the API, enabling a thorough investigation of how the server responds under different circumstances. This ensures our understanding of the robustness and effectiveness of the API under a range of operational conditions.

The robustness of the API's error handling capability was also scrutinized through manual testing. This included providing illegal or invalid inputs and intentionally interrupting the serial connection during operation. This approach guarantees the

### 11 ATHENASECURITY

Screenshot of the "RESTer" REST API testing tool system's resilience in handling unexpected circumstances and its capability to return appropriate responses during such events.

### 12 ATHENASECURITY

# SECURITY CONSIDERATIONS

To ensure a reliable operation of the TRNG, users should consider following things:

1. Make sure the solar cell inside the TRNG is protected from direct sunlight, as this causes the microcontroller to measure maximum voltage.
2. Make sure the TRNG is set on a flat surface, as this can cause the snippets inside the TRNG to change altitude thus stop blocking light to the solar cell.
3. Beware, that the padding of leading zero's when generating numbers which are not divisible by four, changes the outcomes and thus the probability of the first hexadecimal digit of the random number. This should be held in mind when handling such numbers.
4. Make sure to keep the TRNG away from conductive material to prevent the microcontroller from being damaged.
5. The TRNG was not tested in places with very low air humidity, in which the snippets may hold on to the surface of the tunnel.
6. A long-term test over several weeks and beyond was not performed. It is conceivable that the paper snippets wear off due to abrasion, or that the effect of the anti-static spray wears off.

### 13 ATHENASECURITY

# ENVIRONMENT SETUP

The following documentation is divided into two main sections: Development and Production.

1. Development:

The development section of this documentation focuses on setting up and running the system in a development environment. This is where the features are built and tested before they are deployed to the production environment.

2. Production:

The production section of this documentation focuses on preparing the system for a production environment. The features that have been built and tested in the development environment are made production-ready, and the system is set up to handle real-world tra!ic.

Both the "Development" and "Production" sections of this documentation, detailing the system setup and the preparation for a real-world environment, can be found in the appendix (Appendix B - Environment Setup).

### 14 ATHENASECURITY

# USER INTERFACE

The user interface developed with Angular provides a user-friendly and e#icient means of interacting with the hardware-based random number generator. It offers a well-structured layout and intuitive design, facilitating seamless user engagement with the system's functionalities.

The interface incorporates responsive buttons that enable users to initiate requests to the designated API endpoints mentioned earlier. This simplifies the process of interacting with the random number generator, allowing users to trigger specific operations effortlessly. To enhance flexibility and customization, the user interface includes input fields that allow users to enter parameters for the getRandom and generateTestdata endpoints. This enables users to fine-tune their requests and customize the output based on specific requirements or preferences.

Moreover, the user interface includes a convenient feature for downloading the file generated by the generateTestdata endpoint. By clicking the designated "Download File" button, users can conveniently retrieve the generated file for further analysis or integration with other applications.

In the next section, we will walk through the step-by-step instructions on how to retrieve random numbers using the user interface.

### 15 ATHENASECURITY

## STEP BY STEP INSTRUCTIONS

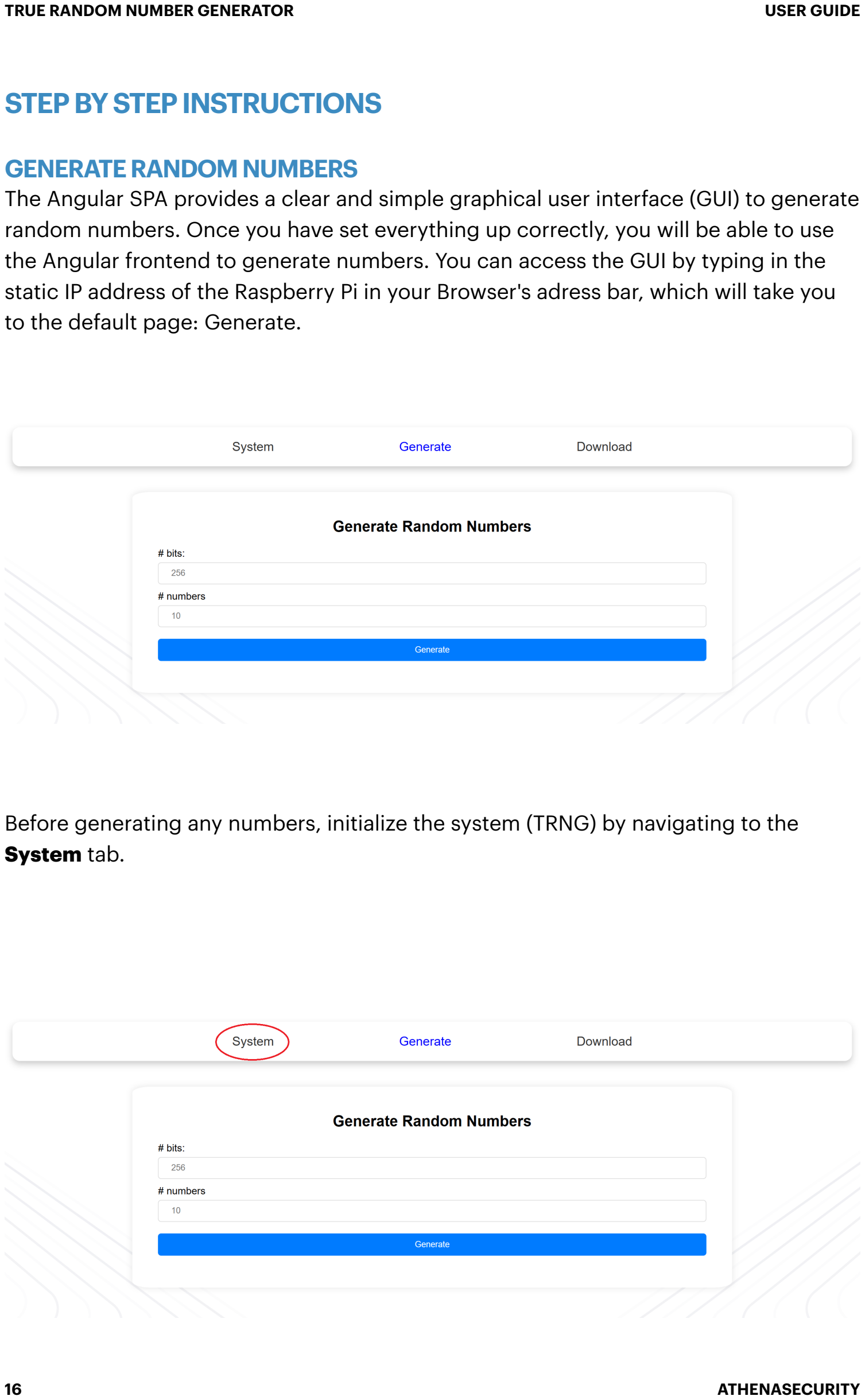
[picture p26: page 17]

### GENERATE RANDOM NUMBERS

The Angular SPA provides a clear and simple graphical user interface (GUI) to generate random numbers. Once you have set everything up correctly, you will be able to use the Angular frontend to generate numbers. You can access the GUI by typing in the static IP address of the Raspberry Pi in your Browser's adress bar, which will take you to the default page: Generate.

Before generating any numbers, initialize the system (TRNG) by navigating to the System tab.

### 16 ATHENASECURITY

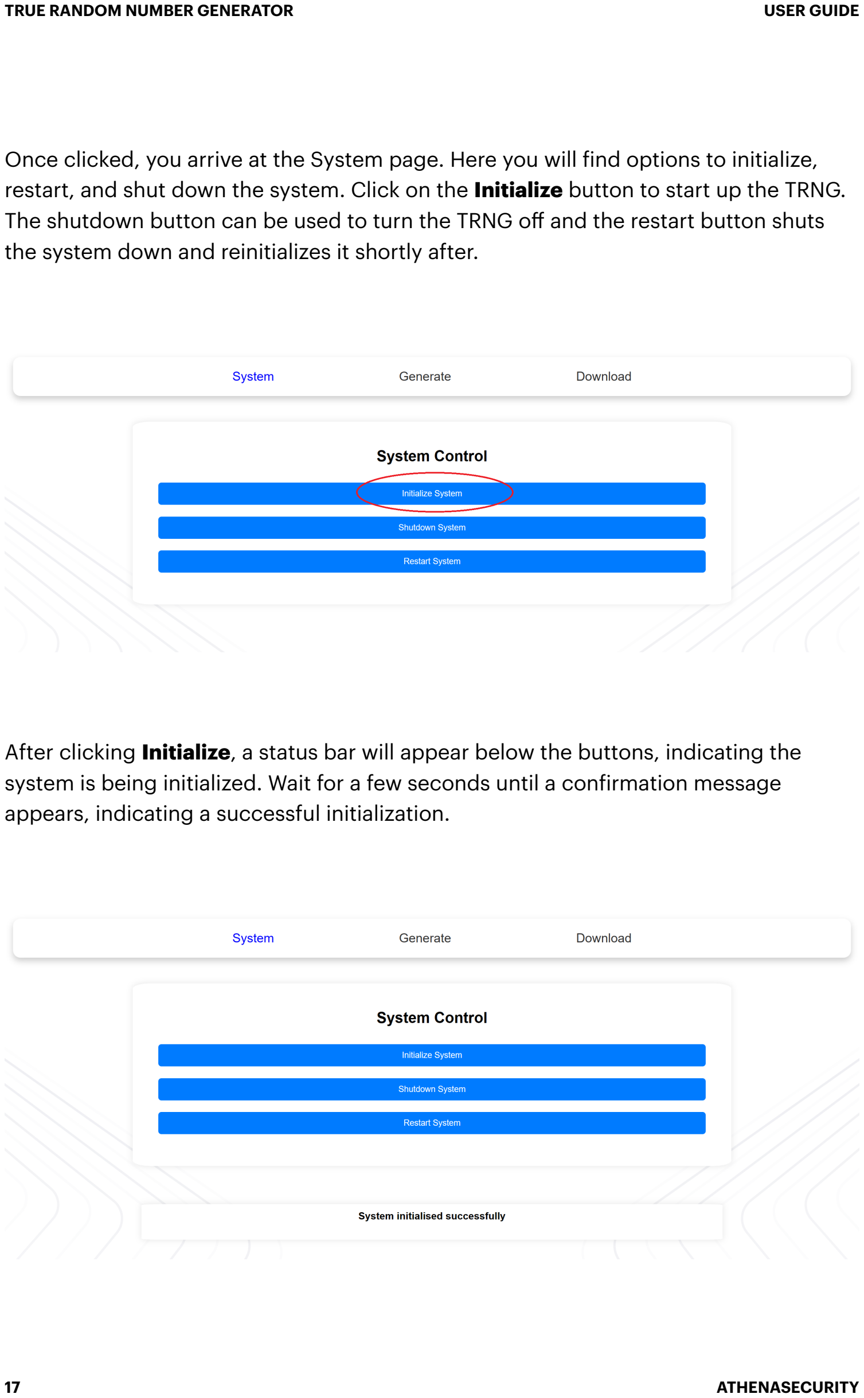
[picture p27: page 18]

Once clicked, you arrive at the System page. Here you will find options to initialize, restart, and shut down the system. Click on the Initialize button to start up the TRNG. The shutdown button can be used to turn the TRNG off and the restart button shuts the system down and reinitializes it shortly after.

After clicking Initialize, a status bar will appear below the buttons, indicating the system is being initialized. Wait for a few seconds until a confirmation message appears, indicating a successful initialization.

### 17 ATHENASECURITY

Return to the Generate page by clicking the Generate tab on the top navigation bar. To generate random numbers, you need to provide two parameters: # bits and
# numbers. The default value for the # bits field is set to '128', representing the length of each random number in bits. For example, if you want to generate 24-bit numbers, simply enter '24' in this field. The # numbers field specifies the quantity of numbers to generate, with a default value of '10'. In this example, we will generate '3' numbers.

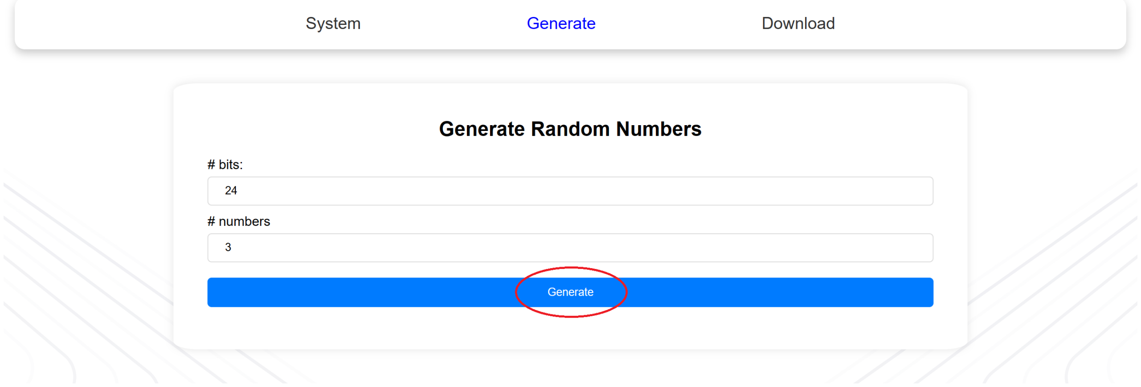
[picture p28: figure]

A status bar will appear, indicating that the numbers are being generated. After the generation is complete, the status bar will confirm the successful generation, and the random numbers will be displayed below.

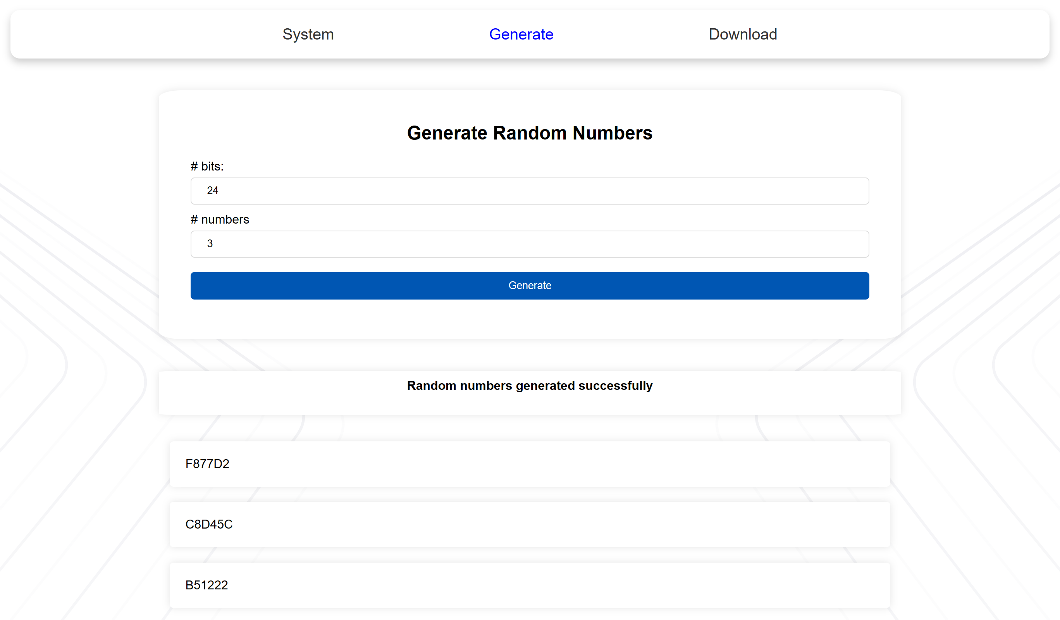
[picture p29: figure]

### 18 ATHENASECURITY

Note: The displayed numbers consist of six characters in hexadecimal format, as each four bits correspond to one hexadecimal digit. If the requested bit length is not divisible by four, it is padded with leading zeros.

### 19 ATHENASECURITY

### DOWNLOAD RANDOM NUMBERS

If you wish to download the generated numbers as a file, navigate to the Download tab.

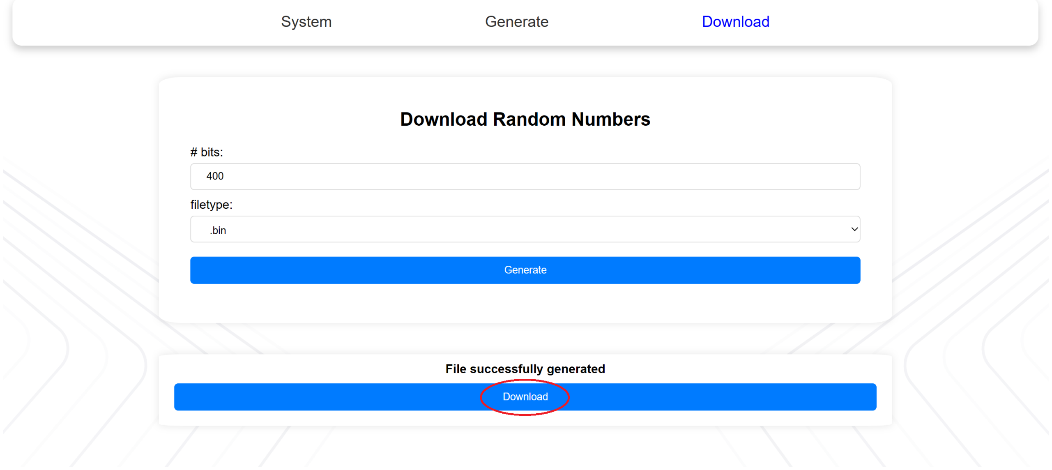
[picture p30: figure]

On the Download page, provide the desired parameters. The first field represents the length of the random number in bits, similar to the Generate page. The default value for this field is '5000'. In this example, we will use '400'.

The second field, filetype, offers a dropdown menu where you can choose between two filetypes: '.bin' (binary) and '.txt' (text). The default selection is '.bin', where random numbers are written as bytes to the file. We will choose '.bin' for this example.

Click the Generate button to initiate the file generation process. Once the generation is complete, the status bar will display the message "File successfully generated" and present a download button. Clicking the download button will prompt your browser to start the download of the file.

### 20 ATHENASECURITY

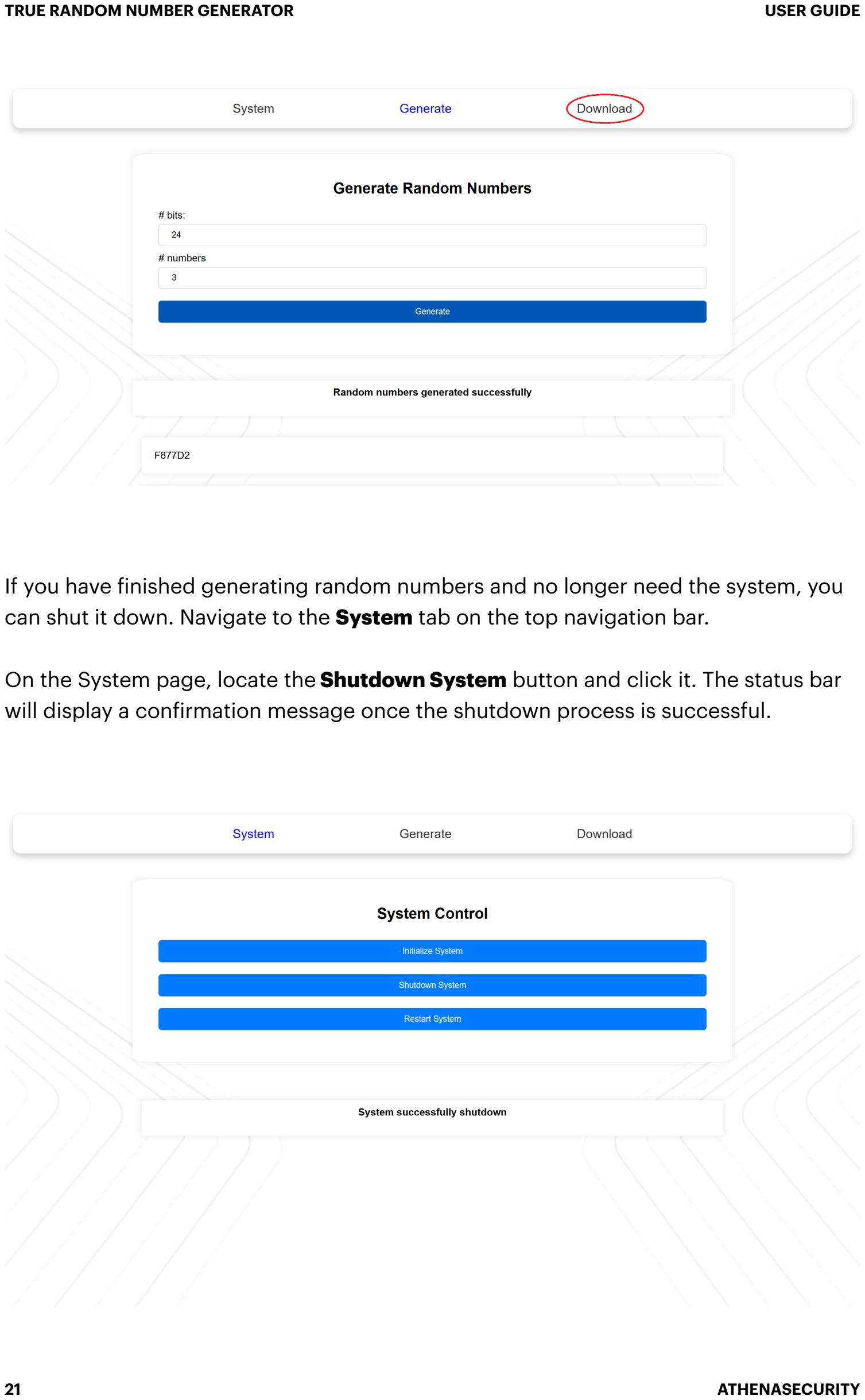
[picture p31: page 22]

If you have finished generating random numbers and no longer need the system, you can shut it down. Navigate to the System tab on the top navigation bar.

On the System page, locate the Shutdown System button and click it. The status bar will display a confirmation message once the shutdown process is successful.

### 21 ATHENASECURITY

By following these step-by-step instructions, you can effectively utilize the Angular SPA's graphical user interface (GUI) to generate random numbers. Remember to initialize the system, input the desired parameters, and navigate through the different tabs for generating numbers, downloading files, and shutting down the system as needed.

### 22 ATHENASECURITY

# CONCLUSION

This user guide provides the necessary information to successfully use the hardware-based random number generator. By following these instructions, users can interact with the hardware device via the Flask API or the Angular user interface to generate random numbers and files of random data.

Furthermore, the system's architecture has been designed with flexibility, robustness, and scalability in mind. The use of Python, Flask, and Angular for this project provides a robust and scalable solution for hardware-based random number generation. The hardware device can be controlled through the Flask API, which is a lightweight and flexible solution, making it easier to add or modify functionality. The use of Angular for the frontend allows for a dynamic and responsive user interface. The choice of Gunicorn and Nginx for serving the application offers stability and security for production deployments. However, they do require additional configuration and may not be necessary for smaller scale applications.

### 23 ATHENASECURITY

## APPENDIX A - ENDPOINTS

### 24 ATHENASECURITY

### Main Endpoint

GET /trng/randomNum/getRandom
This endpoint returns an array of sequences of bits of a specified length and quantity. The API guarantees that the sequences are randomly drawn. The length and quantity of the sequences can be specified using the following query parameters:

numBits (optional, integer, minimum 1, default 1): The number of random bits in each bit sequence.
quantity (optional, integer, minimum 1, default 1): The number of random sequences to generate.
Responses

200 OK: The response is an array of strings, where each string is a randomly generated bit sequence of the specified length. The bit sequences are encoded as hexadecimal strings, with leading zeros if necessary. Example response:

432 Service Unavailable: This error code is returned if the system is not ready to generate random numbers, such as when the random number source is in standby mode or is not reachable.
555 Internal Server Error: This error code is returned if the system is unable to initialize within 60 seconds.

Example Usage

To generate 10 random bit sequences of length 8 using curl, you can run the following command:

[ | "08c1f27b", | "12d45f38", | "9a6b7c5d"]

curl "https://172.16.78.59:8443/trng/randomNum/getRandom?numBits=8&quantity=10"

Appendix A - Endpoints

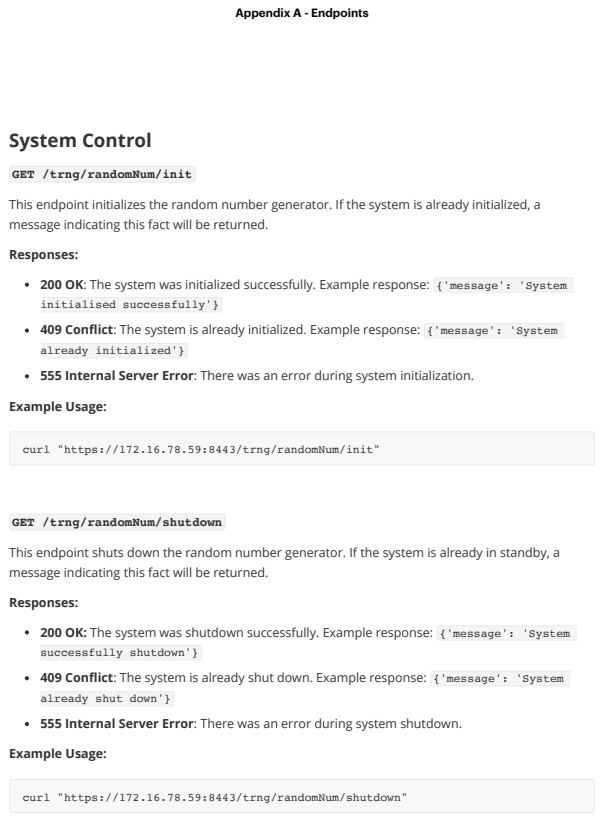
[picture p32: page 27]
System Control; 200 OK: The system was initialized successfully. Example response:; {'message': 'System; initialised successfully'}; 409 Conflict: The system is already initialized. Example response:; 200 OK: The system was shutdown successfully. Example response:; successfully shutdown'}; 409 Conflict: The system is already shut down. Example response:; Appendix A - Endpoints

GET /trng/randomNum/init
This endpoint initializes the random number generator. If the system is already initialized, a
message indicating this fact will be returned.
Responses:

already initialized'}
555 Internal Server Error: There was an error during system initialization.
Example Usage:

curl "https://172.16.78.59:8443/trng/randomNum/init"

GET /trng/randomNum/shutdown
This endpoint shuts down the random number generator. If the system is already in standby, a

already shut down'}
555 Internal Server Error: There was an error during system shutdown.

curl "https://172.16.78.59:8443/trng/randomNum/shutdown"

### Additional Endpoints

GET /trng/randomNum/generateTestdata
This endpoint generates a set of test data. The length and type of the data can be specified using the following query parameters:

numBits (optional, integer, minimum 1, default 5000): The length of the data to generate. filetype (optional, string, default 'bin'): The type of the file to generate.
Responses:

200 OK: The data was generated successfully. Example response: {'message': 'Generation

successful'}
432 Service Unavailable: The system is not ready to generate test data.
555 Internal Server Error: There was an error during data generation.
Example Usage:

GET /trng/randomNum/downloadFile
After calling the /trng/randomNum/generateTestdata endpoint, you can use this endpoint to download a file that contains a set of test data.
Responses:

200 OK: The file download begins.
555 Internal Server Error: The requested file could not be found or there was an error during the file download.
Example Usage:

curl "https://172.16.78.59:8443/trng/randomNum/generateTestdata?numBits=1000&filetype=txt"

curl "https://172.16.78.59:8443/trng/randomNum/downloadFile"

Appendix A - Endpoints

GET /trng/randomNum/restart
This endpoint restarts the random number generator. If the system is already in standby, a message indicating this fact will be returned.
Responses:

200 OK: The system was restarted successfully. Example response: {'message': 'System

successfully restarted'}
555 Internal Server Error: There was an error during system restart.

Example Usage:

Please note that for each of these endpoints, the 555 error code is returned for any exceptions not explicitly caught by the system, indicating an unexpected server error.

curl "http://localhost:5000/trng/randomNum/restart"

Appendix A - Endpoints

## APPENDIX B - ENVIRONMENT SETUP

### 25 ATHENASECURITY

Both sections require certain configurations to establish the serial communication between the Flask API and the hardware device. Therefore a Configuration file located in the root directory of ( .env ) is used to set up the serial communication between the Flask API and the hardware device. The syntax of the configuration files should be as follows:

In the above syntax, port specifies the serial port used to connect to the hardware device, and baud_rate specifies the speed of data transfer in bits per second. Under Linux, you can find out the port used via

On Windows, the Device Manager can be used.

port = "/dev/ttyUSB0"
baud_rate = 9600

ls /dev

Appendix B - Environment Setup

Microcontroller

In this section, we will guide you through the process of setting up a development environment for the NodeMCUv1 board, which forms a key component of the TRNG. Our primary tools will include the official Arduino IDE and a microcontroller code specific to our TRNG, both of which are downloadable from designated repositories.

Requirements: A personal computer with the Legacy Arduino IDE installed. You can download it from the official website. (https://www.arduino.cc/en/software) You'll also need a NodeMCU ESP8266 development board which can be purchased from any reputable electronics supplier. The microcontroller code for the TRNG should be downloaded from the current repository.
1. Clone the Repository
Use the following command to clone the repository:
2. Open the Sketch in the Arduino IDE
Navigate to the downloaded repository location and open the "nodemcu.ino" file.
3. Configure the Arduino IDE to Support the NodeMCU Board
Begin by adding the ESP8266 board manager URL. Go to File > Preferences and in the "Additional Boards Manager URLs" field, add the following link: "http://arduino.esp8266.com/stable/package_esp8266com_index.json". Click OK to save changes. (http://arduino.esp8266.com/stable/package_esp8266com_index.json)
Next, install the ESP8266 board. Navigate to Tools > Board > Boards Manager, search for ESP8266, and proceed with the installation.
4. Select the NodeMCU Board
Go to Tools > Board > ESP8266 Boards > NodeMCU 1.0 (ESP-12E Module).
5. Select the Communication Port
Go to Tools > Port and select the COM Port that your NodeMCU is connected to.
6. Upload the Sketch to the Board
Click the upload button (->) or select Sketch > Upload from the menu.

Upon successful completion of these steps, the LED and fan connected to your NodeMCU board should respond to "on" and "off" commands sent via the serial interface. The board should also transmit processed sensor data when active.

git clone https://github.com/athena-security/cep.git

Appendix B - Environment Setup

API

This section will walk you through setting up a development environment for your Flask API. We will be using a Python virtual environment to encapsulate our development dependencies.

Requirements: A Linux machine with Python installed (You can check the Python version by using the command: python3 --version ). Pip, the Python package installer (Check if pip is installed by using the command: pip3 --version ). If it's not installed, you can install it with sudo apt install python3-pip . Ensure you have the Flask application's source code in the /home/dev/backend/ directory.
1. Create and Activate a Virtual Environment
Python 3 comes with built-in support for virtual environments. You can create a virtual environment using the following command:

Activate the virtual environment:

Your prompt should change to indicate the activated environment.
2. Install Flask and Other Dependencies
With the virtual environment activated, you're ready to install Flask and its dependencies. Assuming you have a requirements.txt file located in /home/dev/backend/ , install these dependencies:
3. Run the Flask Application
1. Run the Application with Flask's Built-in Server
With the dependencies installed, you can now run the Flask application. Navigate to the application directory and run the Flask application:

By default, the Flask application runs on port 5000. You can access it by opening http://12 7.0.0.1:5000 in your web browser. (http://127.0.0.1:5000/)

python3 -m venv /home/dev/backend/backend_env

source /home/dev/backend/backend_env/bin/activate

pip3 install -r /home/dev/backend/requirements.txt

cd /home/dev/backend/
flask run

Appendix B - Environment Setup

2. Run the Application with Gunicorn
Gunicorn is a WSGI HTTP server for Python web applications. If you installed Gunicorn as per the requirements.txt file, you can use it to run the Flask application:

This command will start the Gunicorn server on 127.0.0.1 at port 5000 . Make sure to replace api:app with your application's WSGI entry point. You can now access your application by opening http://127.0.0.1:5000 in your web browser.
4. Develop and Test the API
You can now start developing your API. Use a tool like Postman or curl to test the API endpoints. After making changes to your code, you need to restart the Flask server to see the changes take effect. Remember to deactivate the virtual environment when you're done:

This setup ensures that your development dependencies are isolated from other Python projects on your machine.

cd /home/dev/backend/
gunicorn --bind 127.0.0.1:8000 api:app

deactivate

Appendix B - Environment Setup

Frontend

This section will walk you through setting up a development environment for your Angular application.

Requirements: A Linux machine with Node.js and npm (Node Package Manager) installed. You can check Node.js version using node -v and npm version using npm -v . If not installed, you can download Node.js and npm from here. (https://nodejs.org/en/download) Angular CLI installed globally on your system. You can install it using npm: npm install -g @angular/cli . You can check the Angular CLI version using ng version . Ensure you have the Angular application's source code in the /home/dev/frontend/ directory .
1. Navigate to Your Application Directory
Navigate to the directory where your Angular application's source code is located:
2. Install Dependencies
Angular project dependencies are listed in the package.json file located in the project root directory. You can install these dependencies using npm:
3. Run the Angular Application
You can now start the Angular development server using the Angular CLI:

By default, the Angular application runs on port 4200. You can access it by opening
http://localhost:4200 in your web browser.
4. Develop and Test the Application
You can now start developing your application. The Angular development server automatically watches for file changes and reloads the page. Hence, you can see the changes in real-time in your web browser. Remember to stop the Angular development server when you're done:

This setup ensures that your development dependencies are isolated from other projects on your machine. Happy coding!

cd /home/dev/frontend/

npm install

ng serve

# Press Ctrl+C in the terminal where the server is running

Appendix B - Environment Setup

Static IP

In some network environments, it may be desirable or necessary to assign a static IP address to a machine, instead of relying on dynamic IP assignment via DHCP. A static IP address can be beneficial in cases where the machine needs to be consistently reachable at the same IP, such as for a server or when configuring network hardware.

In this section, we will guide you through the process of setting up a static IP address for your Linux machine. Specifically, we will be configuring the eth0 network interface to use a static IP address. This setup will utilize the dhcpcd network configuration tool, which is pre-installed on most Linux distributions.

Requirements: A Linux machine with dhcpcd network configuration tool installed (most distributions have dhcpcd pre-installed). Root or sudo access to execute the necessary commands.
1. Edit the dhcpcd configuration file
Open the dhcpcd configuration file located at /etc/dhcpcd.conf and paste the following lines at the end of the file:

Add the following configuration for the eth0 interface at the end of the file:

Remember to replace 172.16.78.59/24 with your desired static IP address and CIDR notation. After adding these lines, save and close the file.
2. Restart the dhcpcd service
To apply these changes, you need to restart the dhcpcd service:
3. Verify the IP address assignment
Check the IP address assignment to the eth0 interface:

sudo vim /etc/dhcpcd.conf

# file: /etc/dhcpcd.conf

interface eth0
static ip_address=172.16.78.59/24

sudo systemctl restart dhcpcd

ip addr show eth0

Appendix B - Environment Setup

The output should show the static IP address assigned to the eth0 interface. With this setup, your eth0 interface will now have a static IP address which will persist across reboots.

Appendix B - Environment Setup

Python Virtual Environment

A Python virtual environment is a self-contained directory tree that includes a Python installation and a number of additional packages. The use of a virtual environment is to prevent potential conflicts between system-wide Python packages and the packages used in your particular Python project. In simpler terms, it allows you to create an isolated environment for your Python project, so you can install any package you need without worrying about affecting other Python projects. This is especially useful when working with many different projects that may require different versions of packages.

In this section, we will guide you on setting up a Python virtual environment for your Flask application.

Requirements: A Linux machine with Python installed (You can check the Python version by using the command: python3 --version ). Pip, the Python package installer (Check if pip is installed by using the command: pip3 --version ). If it's not installed, you can install it with sudo apt install python3-pip . Ensure you have the Flask application's source code in the /home/dev/backend/ directory
1. Install Virtual Environment
Python 3 comes with built-in support for virtual environments. You can create a virtual environment using the following command:
2. Activate the Virtual Environment
After creating a virtual environment, you need to activate it:

Your prompt should change to show the name of the activated environment.

3. Install Flask and Other Dependencies
With the virtual environment activated, you can now install Flask and its dependencies. Use pip to install these dependencies:
4. Verify the Instaldlations

python3 -m venv /home/dev/backend/backend_env

source /home/dev/backend/backend_env/bin/activate

pip3 install -r /home/dev/backend/requirements.txt

Appendix B - Environment Setup

You can verify if the packages are installed successfully in your virtual environment by checking the list of installed packages: pip3 freeze . This command should output a list of installed packages along with their versions, including Flask and its dependencies.
Remember to deactivate the virtual environment when you're done:

Now, you have a Python virtual environment set up at /home/dev/backend/backend_env with Flask and its dependencies installed. You're ready to start developing your Flask application within this environment.

deactivate

Appendix B - Environment Setup

API & Gunicorn

Gunicorn is a Python Web Server Gateway Interface (WSGI) HTTP server. It is a pre-fork worker model, which means that it forks multiple worker processes to handle incoming requests. This can provide your Flask application with better concurrency and load handling capabilities. Setting up Gunicorn as a systemd service allows Gunicorn to start on boot, ensuring your web application is always available. It also monitors the Gunicorn processes, automatically restarting them if they crash, thus enhancing the reliability of your application.

This section will guide you on setting up the Gunicorn application server to run as a systemd service.

Requirements: A Linux machine with systemd. Gunicorn and your application installed in a virtual
environment at /home/dev/backend/backend_env . dev user and www-data group existing on the
system. Ensure you have the Flask application's source code in the /home/dev/backend/ directory and root or sudo access to execute the necessary commands.
1. Create a systemd Service File
Systemd service files are located in the /etc/systemd/system directory. Create a new service file for Gunicorn:
2. Add Configuration to the Service File
In the newly created file, add the following lines:

sudo vim /etc/systemd/system/gunicorn.service

# file: /etc/systemd/system/gunicorn.service [Unit]

Description=Gunicorn server instance After=network.target

[Service]
User=dev
Group=www-data
WorkingDirectory=/home/dev/backend/ Environment="PATH=/home/dev/backend/backend_env/bin" ExecStart=/home/dev/backend/backend_env/bin/gunicorn --access-logfile - --error-logfile - --log-level debug --timeout 900 --workers 1 --bind 127.0.0.1:8000 api:app

[Install]
WantedBy=multi-user.target

Appendix B - Environment Setup

This configuration specifies that we want to start the Gunicorn service after the network target has been reached during the boot process. It also sets the user and group that will run the service, sets the working directory, and specifies the command to start Gunicorn.
Ensure that the paths for WorkingDirectory , Environment , and ExecStart point to the correct locations for your setup. Save and close the file.
3. Enable and Start the Gunicorn Service
Now that we have our systemd service file, we can tell systemd to start it during the boot sequence:

You can also start the service manually without rebooting:

4. Check the Status of the Gunicorn Service
To verify that the service is running as expected, you can use:

The output should indicate that the service is active and running. Now, Gunicorn will start on boot and will be managed by systemd.

sudo systemctl enable gunicorn

sudo systemctl start gunicorn

sudo systemctl status gunicorn

Appendix B - Environment Setup

Frontend & Nginx

Nginx is a powerful, high-performance HTTP server and reverse proxy server. It can serve static files and can also proxy requests to other servers, making it a versatile tool for both serving and routing HTTP requests.

In the following steps, we will be setting up two Nginx server blocks. The first server block will serve as a web server listening on port 443, typically used for serving secure HTTP traffic. The second server block will act as a reverse proxy server listening on port 8443, forwarding requests to a backend service running on http://127.0.0.1:8000. This setup allows you to use Nginx to serve your web application and to route requests to your Flask API.

It's important to note that in a production setup, port 443 is typically used for serving secure HTTP traffic over SSL/TLS. As we're using a self-signed certificate in this setup, your browser may display a warning about the site's security. This is expected behavior. In a live, public-facing server environment, you'd want to use a certificate issued by a trusted certificate authority to avoid this warning. However, for development, testing, and internal use, a self-signed certificate can be sufficient.

Requirements: Nginx and a web application ready to be served at /var/www/html/trng-frontend and the gunicorn server with the backend up and running.

1. Build the Angular Application
Navigate to your Angular application directory and build your Angular application using the Angular CLI. The --prod flag will cause Angular to build in production mode, optimizing the build for production:

The built files will be stored in the dist/ directory inside your project folder.
2. Move the Built Files to the Nginx's Root Directory
Copy the built files to the root directory of the Nginx server. In the provided Nginx configuration, the root directory is /var/www/html/trng-frontend . You may need to create this directory if it does not exist:
3. Generate SSL Certificates

cd /home/dev/frontend/
ng build --configuration production

sudo mkdir -p /var/www/html/trng-frontend sudo cp -r dist/* /var/www/html/trng-frontend/

Appendix B - Environment Setup

Firstly, we need to generate a SSL certificate and key. We can use the OpenSSL toolkit to generate a self-signed certificate. Run the following command, and it will create a certificate and key in your current directory.

This will start an interactive script which will ask you for various bits of information. Fill it out as you see fit. These fields are not critical for a self-signed certificate. Make sure you move the trng.crt and trng.key files to the /etc/nginx/ssl directory, or adjust the nginx configuration file to point to the location where you've stored your certificates and keys.
After running this command, move the generated trng.crt and trng.key files to the
/etc/nginx/ssl directory:
4. Create Nginx Config File
Navigate to the Nginx directory containing site configurations and create a new configuration
file. This is usually /etc/nginx/sites-available .
5. Paste Configuration
Copy the given configuration into the file. Ensure that the SSL certificates and key files referenced in the configuration are at the specified location in your file system. Save and close the file.

openssl req -x509 -newkey rsa:4096 -nodes -out trng.crt -keyout trng.key -days 365

sudo mkdir -p /etc/nginx/ssl
mv trng.crt trng.key /etc/nginx/ssl/

sudo vim /etc/nginx/sites-available/trng.conf

# file: /etc/nginx/sites-available/trng.conf server {

listen 443 ssl;
server_name $domain_name;

ssl_certificate /etc/nginx/ssl/trng.crt; ssl_certificate_key /etc/nginx/ssl/trng.key;

location / {
root /var/www/html/trng-frontend; try_files $uri $uri/ /index.html; }
}

server {

Appendix B - Environment Setup

Save and close the file.
6. Enable the Site
Create a symbolic link to this file in the /etc/nginx/sites-enabled directory.
7. Test Nginx Configuration
Before applying the changes, check if the Nginx configuration is correct. If the configuration is
correct, you should see: nginx: configuration file /etc/nginx/nginx.conf test is

successful

If there are errors in your configuration, the nginx -t command will output them and highlight the lines in the files where they are located. Correct these errors before you proceed.
8. Reload Nginx
Once the configuration test is successful, reload the Nginx service to apply the changes.

The setup is now complete. You can test the setup by navigating to your domain on a web browser. Remember that you have configured two different ports, 443 and 8443, so you might want to test both ports to ensure your setup is working correctly.

listen 8443 ssl;
server_name $domain_name;

ssl_certificate /etc/nginx/ssl/trng.crt; ssl_certificate_key /etc/nginx/ssl/trng.key;

location /trng/ {
proxy_pass http://127.0.0.1:8000;
proxy_set_header Host $host;
proxy_set_header X-Real-IP $remote_addr;
proxy_set_header X-Forwarded-For $proxy_add_x_forwarded_for; proxy_set_header X-Forwarded-Proto $scheme;
proxy_set_header X-Forwarded-Port $server_port;

}
}

sudo ln -s /etc/nginx/sites-available/trng.conf /etc/nginx/sites-enabled/

sudo nginx -t

sudo systemctl reload nginx

Appendix B - Environment Setup

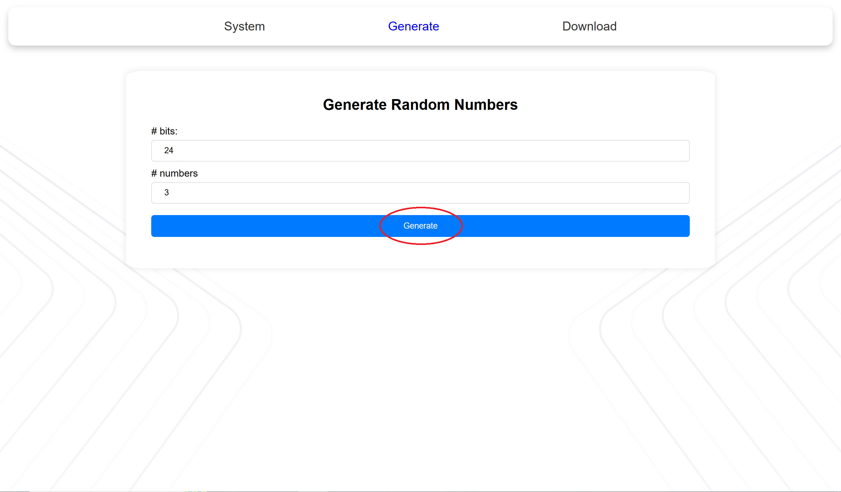
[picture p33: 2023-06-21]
01-Documentation/01-UserGuide/screenshots/frontend/generate_page_filled.PNG

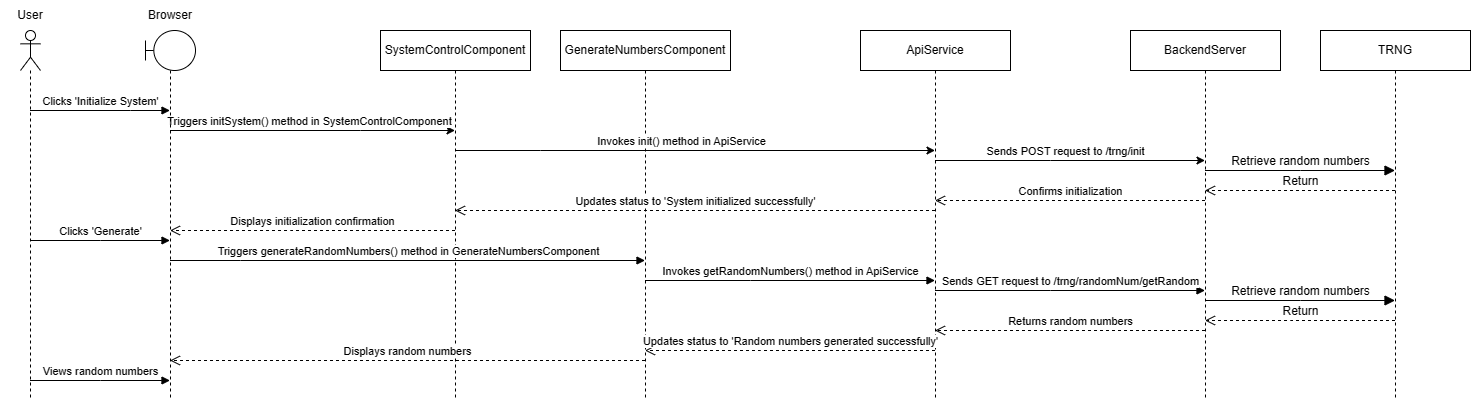
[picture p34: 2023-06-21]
01-Documentation/01-UserGuide/diagrams/sequence_diagram.png

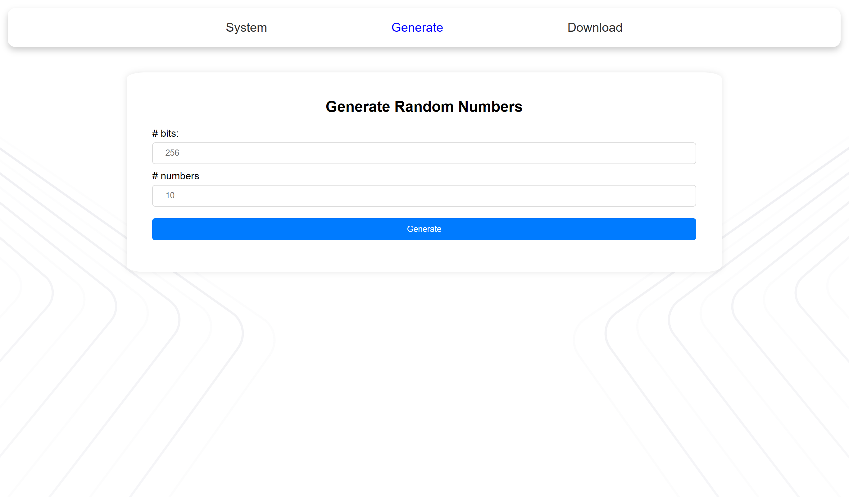
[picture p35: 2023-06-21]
01-Documentation/01-UserGuide/screenshots/frontend/generate_page_empty.PNG

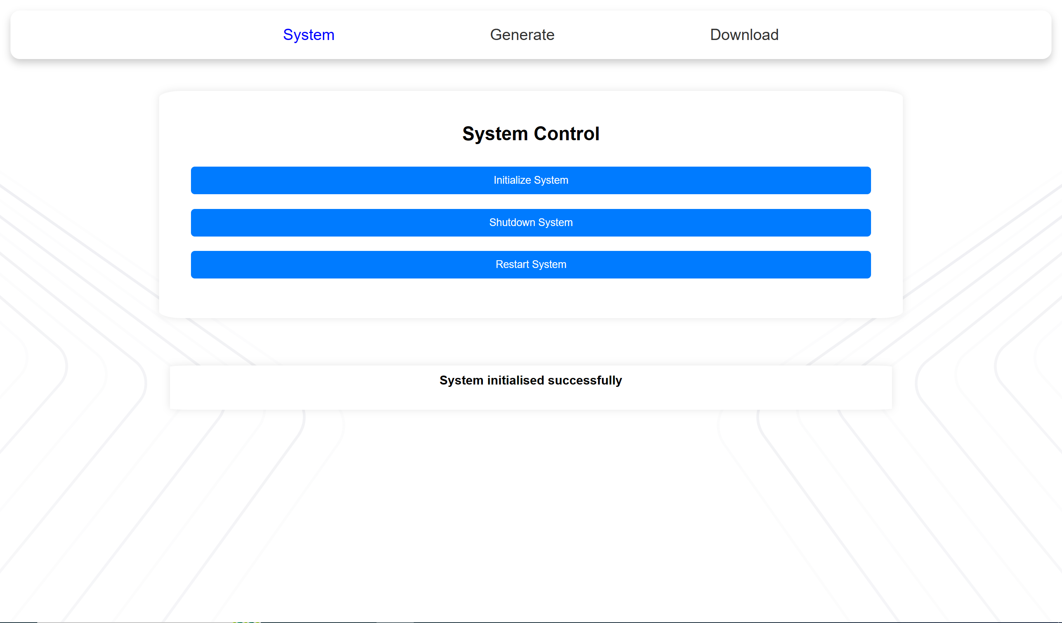
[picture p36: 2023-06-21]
01-Documentation/01-UserGuide/screenshots/frontend/system_page_successful_init.PNG

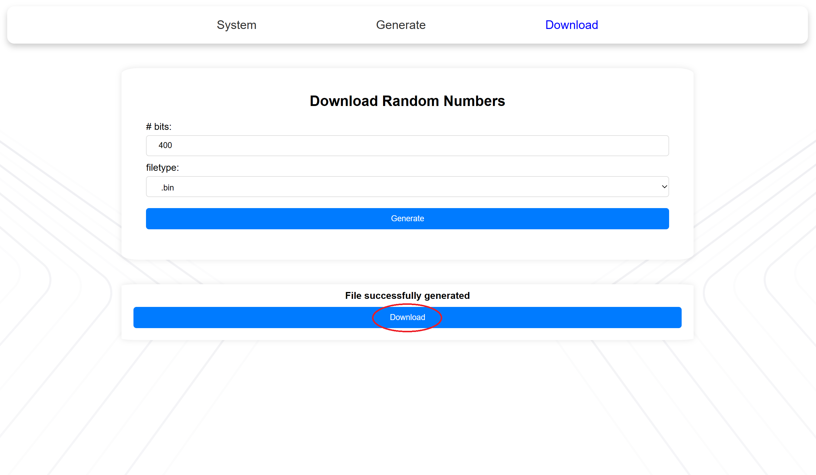
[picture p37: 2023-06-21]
01-Documentation/01-UserGuide/screenshots/frontend/download_page_download_button.PNG

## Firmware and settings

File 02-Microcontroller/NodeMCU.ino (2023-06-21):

//pins on the NodeMCU for the led and fan
int ledPin = 4;
int fanPin = 5;

String incoming; //string holds the incoming serial commands "on"/"off"
int sensorValue = 0;  //variable to store the value coming from the sensor

void setup() {
  delay(1000);
  //configure led and fan as output and turn them off by default
  pinMode(fanPin, OUTPUT);
  digitalWrite(fanPin, LOW);
  pinMode(ledPin, OUTPUT);
  digitalWrite(ledPin, LOW);
  Serial.begin(9600);  //start the serial communication with 9600 baudrate
  delay(1000);
}

void loop() {
  
  static bool active = false; //stores the state of fan and led

  if (Serial.available() > 0) { //As soon as something is received via the serial interface
    incoming = Serial.readString();
    if (incoming == "on") { //activate fan and led when "on" is received
      digitalWrite(fanPin, HIGH);
      digitalWrite(ledPin, HIGH);
      delay(2000);
      active = true;
    } else if (incoming == "off") { //deactivate fan and led when "off" is received
      digitalWrite(fanPin, LOW);
      digitalWrite(ledPin, LOW);                      
      active = false;
    }
  }


  if (active) { //only run the code, when led and fan are on
    
    byte data = 0; //byte which is filled with random bits and later send to the API

    //the loop variable is used later to check if one Byte is filled with Bits before sending it
    for (int i = 0; i < 50; i++) {
      
     for (int a = 0; a < 4; a++) { //read the solar voltage 4 times with an interval of 5ms 
      int reading = analogRead(A0); //convert the solar voltage to int number (0V=0 |3.3V =1023)
      sensorValue = sensorValue + reading; //add the last reading to sensorValue
      delay(8); //wait 8ms (4 x 8ms = 32ms for full sensorValue)
    }

      byte lsb = (sensorValue & 0b11); //extract two LSBs from sensorValue
      sensorValue = 0; //clear sensorValue
      data = (data << 2) | lsb; //Add the two last extracted LSBs to data (Byte)
  
      if (i % 4 == 3) { //check if data (Byte) is filled with 8 LSBs
        Serial.write(data); //send the byte via the serial interface
        data = 0; //reset the byte after it has been sent
      }
    }
  }
}

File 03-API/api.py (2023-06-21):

"""
Main entry point for the application.
"""

import system
from routes import app

if __name__ == '__main__':
    try:
        # Initialize the system before running the app
        system.prep()
        # Run the Flask application
        app.run()
    except Exception as e:
        print(f"An error occurred while running the application: {str(e)}")
